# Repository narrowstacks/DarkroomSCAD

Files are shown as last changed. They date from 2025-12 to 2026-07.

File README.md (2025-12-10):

# DarkroomSCAD

## Open source 3D models for darkroom equipment

This project provides a collection of open-source 3D models for darkroom equipment, designed using OpenSCAD. The models are parametric, allowing for customization to fit various needs and film formats. Whether you need negative carriers, film developing tools, or other darkroom accessories, this library aims to provide a versatile and adaptable set of designs for the analog photography community.

## Getting Started

These instructions will help you get a copy of the project up and running on your local machine for development and testing purposes.

### Prerequisites

Before you begin, ensure you have the following installed and configured:

- **OpenSCAD (Nightly Build):** This project requires features available in the nightly builds of OpenSCAD. The latest stable release is not compatible. You can find the nightly builds on the [OpenSCAD downloads page](https://openscad.org/downloads.html) (look further down the page).
- **BOSL2 Library:** This project relies on the BOSL2 library. You can find it at [https://github.com/revarbat/BOSL2](https://github.com/revarbat/BOSL2). Please ensure it is correctly installed and accessible by OpenSCAD.
- **Included Files:** Some `.scad` files may require other specific files to be present in the same directory or a properly configured library path. For example, `omega-d.scad` requires `film-sizes.scad` and `common-carrier-features.scad`.

## Installation

1.  **Download OpenSCAD:**
    - Go to the [OpenSCAD downloads page](https://openscad.org/downloads.html).
    - Download and install the **latest nightly build** suitable for your operating system.
2.  **Install BOSL2 Library:**
    - Follow the installation instructions provided on the [BOSL2 GitHub repository](https://github.com/revarbat/BOSL2). This typically involves cloning the repository or downloading a release and placing it in your OpenSCAD libraries folder.
3.  **Project Files:**
    - Clone or download this repository.
    - Ensure that any accompanying `.scad` files (like `film-sizes.scad` or `common-carrier-features.scad`) are located where the main `.scad` files can find them (e.g., in the same directory or a common library folder).

## Configuration

For optimal performance and to ensure all features work correctly, please configure the following in OpenSCAD:

1.  **Enable Text Metrics:**
    - Go to OpenSCAD `Preferences`.
    - Under the `Features` tab (or similar, depending on the OpenSCAD version).
    - Ensure that `textmetrics` is enabled.
2.  **Set 3D Rendering Engine:**
    - Go to OpenSCAD `Preferences`.
    - Change the `3D rendering engine` to `"Manifold (new/fast)"`. This can significantly speed up the rendering of complex files.

## Usage

To use the `.scad` files in this project:

1.  **Open the File:** Open the desired `.scad` file (e.g., `negative_carriers/carrier.scad`) in OpenSCAD.
2.  **Customize Parameters:** Most `.scad` files will have a section at the top for customization. You can adjust these parameters to suit your needs. 
    - _(Refer to the specific `.scad` file for a full list of available parameters and their descriptions.)_
3.  **Render and Export:**
    - Once customized, you can preview the model in OpenSCAD (usually by pressing F5 for preview or F6 to render).
    - To generate an STL file for 3D printing, choose `File > Export > Export as STL...`.

## Contributing

Contributions are welcome! If you'd like to contribute, please follow these general guidelines:

- **Fork the Repository:** Start by forking the main repository.
- **Create a Branch:** Create a new branch for your feature or bug fix.
- **Code Style:** Try to maintain a consistent code style with the existing codebase. Comment your code where necessary.
- **Test Your Changes:** Ensure your changes work as expected and do not introduce new issues.
- **Submit a Pull Request:** Once your changes are ready, submit a pull request with a clear description of the changes and why they were made.

## License

[This project is licensed under the MIT License.](LICENSE)

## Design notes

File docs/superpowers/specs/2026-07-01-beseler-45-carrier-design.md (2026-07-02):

# Beseler 45 Negative Carrier — Design Spec

**Date:** 2026-07-01
**Status:** Implemented

## Goal

Add a fully working `beseler-45` carrier type to the DarkroomSCAD generator,
replacing the current "not yet implemented" placeholder. The Beseler 45 is a
round, hinged clamshell carrier for the Beseler 45-series (4×5) enlargers. Our
printed version reproduces it as **two separate peg-mated boards** (no hinge).

The implementation follows the existing `beseler-23c` carrier as its template:
round body + protruding handle + handle-mounted text + the shared universal
assembly pipeline. The Beseler 45 adds one thing the 23c does not have: a
second, fixed peg system for enlarger alignment / board stacking.

## Reference dimensions

From `negative-carriers/beseler-45-dimensions.md` and scans of the physical
top/bottom boards:

- Body diameter: **210 mm** (radius 105)
- Handle: **29 mm** wide × **50.5 mm** long
- Board thickness (each half): **2.5 mm** (all other carriers are 2 mm)
- Corner align/stack pegs: **Ø4.6 mm**, **119.7 mm** center-to-center square
  (so each peg sits at ±59.85 mm on X and Y)
- Corner peg holes in the top board: **Ø6 mm**

## Decisions (resolved during brainstorming)

1. **Two peg systems, both modeled:**
   - *Film pegs* — the existing film-format-driven registration pegs (same code
     path as omega/lpl/23c). They register the film and mate the two halves.
     Honor the `Printed_or_Heat_Set_Pegs` option as usual.
   - *Corner align/stack pegs* — new, fixed 119.7 mm square, Ø4.6 mm. The
     **bottom** board carries pegs that protrude **down only (~2 mm)** to seat
     into the enlarger, with a domed (rounded) tip for easy insertion; the upper
     end stays flush inside the board. The **top** board's matching Ø6 mm corner
     holes are **stacking holes** — they receive the down-pegs of another
     carrier stacked on top. Always present, independent of the film-peg style.
     (Earlier revisions had the peg protrude up into the top board as well; that
     was dropped — the film pegs mate the two halves, the corner pegs only
     handle enlarger seating + stacking.)
2. **No alignment board.** The corner pegs are the enlarger alignment; the
   `beseler-45` dispatch forces `Alignment_Board = false` and skips the
   omega/lpl screw-footprint holes. The 4 corner rivets on the real part are
   construction fasteners and are not modeled.
3. **No hinge.** Top and bottom print as two separate pieces, mated by pegs.
4. **No hang hole; solid handle** (matches the 23c).
5. **Handle text** — owner/type etch on the **top (+Y)** handle. Same idea as the
   23c but positioned on the top handle instead of the 23c's −X handle, so it
   needs its own positioning branch (see below).
   - **As implemented:** `get_text_rotation` uses `[0, 0, 90]`, as planned. But
     since `universal-carrier-assembly.scad` applies the transforms as
     `rotate(rotation) translate(position)` — i.e. rotation is the *outer*
     transform — the pre-rotation position tuple in `calculate_text_position`
     had to be swapped to `[handle_mid_y, -x_base, z_position]` (rather than
     `[x_base, handle_mid_y, z_position]`) so that `R(90°) * [a, b] = [-b, a]`
     lands the text at the intended world position on the top handle. Verified
     by the 4×5 renders in Task 4: text sits correctly on the top handle with
     no rotation-composition drift.
6. **4×5 is landscape-only.** For the Beseler 45, 4×5 must render landscape —
   the 5″ (long) edge parallel to the bottom hinge line (i.e. the long edges on
   the top and bottom), hinge at the bottom, handle at the top. This is already
   the effective behavior: 4×5 is globally forced to the code's `"vertical"`
   effective orientation, which yields `cuboid([120, 95])` = 120 mm along X ×
   95 mm along Y = landscape with the long edges horizontal, and the Orientation
   control is ignored for 4×5. So **no orientation-logic change is required** —
   the requirement is satisfied by placing the handle at the top (decision 5/
   base shape) and must be **confirmed visually** during validation.

## Architecture

The Beseler 45 slots into the existing modular pipeline exactly like the 23c,
with a single carrier-type-gated addition for the corner pegs.

### New file: `src/beseler-45-base-shape.scad`

Pure geometry generator, mirroring `beseler-23c-base-shape.scad`:

- `module beseler_45_base_shape(config, top_or_bottom)`
- Uses shared constants `BESELER_45_DIAMETER` (210) and
  `BESELER_45_HANDLE_WIDTH` (29); handle length 50.5 mm.
- Round body via `cyl(h=CARRIER_HEIGHT, r=DIAMETER/2, rounding=.5, $fn=72)`.
- Handle via a rounded `cuboid`. **Handle placed at the top (+Y)**, NOT on the
  −X side like the 23c. This makes the handle define "top" and the opposite edge
  (−Y) the conceptual hinge/bottom, so the 4×5 landscape opening's long edges
  land on the top/bottom. No hang hole.
- Carrier height comes from `get_carrier_height("beseler-45")` = 2.5.

### `src/carrier-configs.scad`

- **Fix bug:** `BESELER_45_DIAMETER = 105` → **`210`** (the base-shape convention
  is `r = DIAMETER/2`; 105 would produce a half-size disc).
- `get_carrier_height`: return `BESELER_45_THICKNESS` (2.5) for `beseler-45`
  (currently everything returns the universal 2). Verify no downstream
  calculation assumes a 2 mm height for this carrier.
- `get_top_peg_hole_z_offset`: give `beseler-45` a value (mirror the 23c's `1`
  unless testing shows otherwise).
- Text: add `beseler-45` to `_get_text_settings` and add a `beseler-45` branch in
  `calculate_text_position` that mounts the text on the **top (+Y)** handle
  (owner/type stacked along the handle's Y length, centered in X), plus a
  `get_text_rotation` case (horizontal text reading left-to-right across the top
  handle). This differs from the 23c branch, which mounts text on the −X handle.
  Ensure the text-feature gate (`_is_full_feature_carrier` /
  `carrier_supports_multi_material_text`) allows beseler-45 text without
  re-enabling alignment-board support.
- Add new constants for the corner pegs:
  - `BESELER_45_ALIGN_PEG_SPACING = 119.7` (center-to-center)
  - `BESELER_45_ALIGN_PEG_DIAMETER = 4.6`
  - `BESELER_45_ALIGN_PEG_HOLE_DIAMETER = 6`
  - up/down protrusion heights (sane defaults, ~4 mm each), tunable.

### `src/common/universal-carrier-assembly.scad`

- `include <../beseler-45-base-shape.scad>`.
- Add a `beseler-45` branch in `generate_universal_base_shape`.
- New module (e.g. `generate_beseler45_corner_pegs()`), gated to
  `carrier_type == "beseler-45"`:
  - **Bottom** assembly: union the 4 corner pegs (protrude down + up).
  - **Top** assembly: subtract the 4 Ø6 mm corner holes.
  - Placed inside the assembly modules so it inherits the
    `Flip_Bottom_For_Printing` rotation. Independent of the film-peg z logic —
    the corner peg needs explicit down/up protrusion, not the film-peg offset.

### `carrier.scad`

- `include <src/beseler-45-base-shape.scad>`.
- Replace the placeholder `assert` branch (currently ~lines 216–218) with a real
  dispatch. Reuse `dispatch_to_universal_assembly` but force
  `_alignment_board = false` and `_alignment_board_type = "none"`, so the corner
  pegs are the only alignment feature. Add `beseler-45` to the standard-carrier
  branch or give it its own branch.

## Component boundaries

- **Base shape** (`beseler-45-base-shape.scad`): knows only the disc + handle
  outline. No openings, no pegs. Depends on the shared diameter/handle
  constants.
- **Corner pegs** (in the assembly layer): a self-contained feature that adds
  pegs (bottom) or holes (top) at fixed positions. Depends only on the corner
  peg constants and `top_or_bottom`.
- **Film pegs / opening / text / dispatch**: unchanged shared machinery; the
  Beseler 45 is just another carrier type flowing through it.

## Testing / validation

- Open `carrier.scad` in OpenSCAD, set `Carrier_Type = "beseler-45"`.
- Render **top** and **bottom** for several formats (35mm, 6x6, 6x9, 4x5) in
  both orientations. Verify:
  - Disc is 210 mm across, 2.5 mm thick, handle 29 mm wide, handle at the top.
  - Film pegs track the format and mate top↔bottom.
  - Bottom board shows 4 corner pegs (down + up); top board shows 4 Ø6 mm holes
    at the matching 119.7 mm square. Corner pegs clear the opening at every
    format including 4×5.
  - **4×5 renders landscape** — long (120 mm) edges on the top and bottom
    (parallel to the −Y hinge line), handle at the top; the Orientation control
    does not change 4×5.
  - No alignment-board geometry or screw-footprint holes appear.
  - Handle text etches correctly (owner + type) on the top handle.
  - `Flip_Bottom_For_Printing` flips the bottom board with its corner pegs.
- Confirm the other carrier types (omega-d, lpl, 23c, test frame) still render
  unchanged.

## Deferred / out of scope

- Hinge, hang hole, and the 4 construction rivets are intentionally not modeled.

## Resolved non-issues

- **Corner pegs vs. 4×5 opening:** no collision. The pegs sit on the diagonal
  corners at (±59.85, ±59.85); the largest opening (4×5 landscape) reaches only
  (60, 47.5). A peg would clip the opening only if both its X and Y ranges
  crossed the opening, but at 4×5 the peg's Y (59.85) clears the opening's
  47.5 mm half-height by ~10 mm. Clears at every format.

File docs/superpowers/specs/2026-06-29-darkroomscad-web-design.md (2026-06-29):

# DarkroomSCAD Web — Design Spec

**Date:** 2026-06-29
**Status:** Approved (brainstorming complete; next step: implementation plan)
**Author:** Aaron + Claude

## Summary

A standalone website that lets analog photographers configure and export 3D-printable
negative carriers from the DarkroomSCAD parametric models — without touching code. Users
pick their enlarger, film format, name/text, font, and options through a guided form, see a
live 3D preview, and download print-ready STL files. The site runs OpenSCAD entirely in the
browser via WebAssembly and deploys to Vercel as an effectively static app (no backend, no
per-render server cost).

This lives in a **new, separate repository** (`darkroomscad-web`) that pulls `.scad` source
from the DarkroomSCAD repo at a pinned ref. This spec document is committed to the
DarkroomSCAD repo as the planning artifact of record.

## Goals

- Non-technical photographers can produce a working carrier STL set in a few clicks.
- Live, interactive 3D preview that updates as parameters change.
- Export the complete set of parts needed to print a real carrier (top + bottom +
  alignment board + multi-material text parts as applicable).
- Visual design that feels like a sibling to [dorkroom](https://dorkroom.art).
- Architecture extensible to other DarkroomSCAD product families (lens boards, Paterson
  tank, thermometer holder) later — but ship **negative carriers only** first.

## Non-Goals (v1)

- No in-browser code editor / SCAD source editing (guided customizer only).
- No product families beyond negative carriers (architect for extension; don't build yet).
- No server-side / serverless rendering (explicitly rejected — see Decisions).
- No user accounts, saved configs server-side, or e-commerce.

## Key Decisions (from brainstorming)

| Decision | Choice | Rationale |
|---|---|---|
| UX model | **Guided customizer** (no code editor) | Audience is photographers, not coders; product feel |
| Catalog scope | **Negative carriers only**, extensible | Most complex/used design; ship focused |
| 3D preview | **Live in-browser preview** | Best product feel; WASM makes it free/client-side |
| File sync | **Build-time fetch/copy script** | Reproducible, pinned, separate repos stay decoupled |
| Export unit | **ZIP (default) or individual files, user choice** | ZIP matches how carriers are actually printed |
| Rendering | **Fully client-side WASM** (Approach A) | No backend, infinite scale, zero render cost |
| Engine | **Official OpenSCAD 2025.03.25 prebuilt WASM** (Manifold + textmetrics) | Importable factory; ~7-8× faster than fast-csg |
| Framework | **Next.js (App Router) on Vercel** | Native Vercel fit; match dorkroom's *look*, not its stack |

### Rejected approaches

- **Serverless rendering (Approach B):** native OpenSCAD in Vercel functions → cold starts,
  function timeouts on large (4x5) renders, per-render cost. Loses the static-site advantage.
- **Fork openscad-playground (Approach C):** architected around a Monaco editor + PrimeReact,
  fights the clean guided-form UX. Used only as a *reference* for known-good WASM/font setup.

## Architecture

### 1. Repo & stack

New repo `darkroomscad-web`:

- **Next.js (App Router) + TypeScript**, deployed on Vercel (effectively static).
- **react-three-fiber + drei** — 3D viewer.
- **fflate** — client-side ZIP.
- **Tailwind CSS** — styling, with a custom theme mirroring dorkroom's tokens.
- **openscad-wasm** (pinned release) — OpenSCAD in a Web Worker.
- All OpenSCAD execution is client-side in a Web Worker. No backend.

### 2. File-sync & build pipeline

`scripts/sync-scad.ts`, run at build time:

- Fetches `carrier.scad` + `src/**` from the DarkroomSCAD repo at a **pinned ref**
  (`DARKROOMSCAD_REF` env var, default a tag/commit SHA). Supports `--local ../DarkroomSCAD`
  for local dev against a working tree.
- Writes the SCAD tree into `public/scad/` (mounted into the WASM virtual filesystem).
- Parses `carrier.scad`'s customizer annotations (`/* [Section] */`, `// [opt,opt]` dropdowns,
  numeric ranges, defaults, comments-as-help) into `generated/param-schema.json`.

Pinning the ref makes builds reproducible; updating the design is a deliberate ref bump.

### 3. Parameter system (auto-parse + curation overlay)

Two layers keep the form both in-sync and clean:

- **`generated/param-schema.json`** — raw truth, auto-derived from `carrier.scad`.
- **`config/carrier-ui.ts`** — hand-maintained curation overlay controlling:
  - Which params are exposed vs. hidden (e.g. hide `TEXT_ETCH_OVEREXTRUDE`; tuck raw text
    offsets behind an "Advanced" disclosure).
  - Friendly labels, help text, grouping, order, step sizes.
  - **Fonts:** replace the free-text `Fontface` param with a dropdown of **bundled open
    fonts only** (we can only render fonts mounted into the WASM FS). The DarkroomSCAD default
    `Lucida Console` is proprietary and must be remapped to a bundled font (e.g. a Liberation
    or DejaVu mono).
  - Conditional visibility: Custom Film Format fields only when `Film_Format=="custom"`;
    `Alignment_Board_Type` only when `Alignment_Board==true`; etc.

A **build-time consistency check** fails the build if the overlay references a param that no
longer exists in the generated schema — so renaming a parameter in the SCAD source can't
silently break the site.

### 4. WASM render engine

`lib/openscad/worker.ts` — a Web Worker wrapping a **pinned `openscad-wasm` release**
(manifold backend; must be a `textmetrics`-capable, nightly-tracking build). On init it mounts
a virtual filesystem containing:

- The synced SCAD tree (`carrier.scad` as the main file, `src/` relative to it).
- **BOSL2** (pinned version) on the OpenSCAD library path.
- **Bundled fonts** + fontconfig so `text()` and `textmetrics()` resolve.

Render API:

```ts
render({ params, quality, part }) -> { stl: Uint8Array, log: string, durationMs: number }
```

- Parameters passed via a written **params JSON** (OpenSCAD customizer parameter set,
  `-p params.json -P set`) for robust escaping of names/strings.
- Manifold backend; `quality` maps to `Render_Quality` + `$fn`.
- Worker **serializes** renders and supports **cancellation** (newest request wins / debounced).

### 5. Preview & viewer

- On parameter change (debounced ~400ms): request a **fast preview** render
  (`Render_Quality="preview"`, low `$fn`, single representative part).
- Resulting STL streams into a **react-three-fiber** viewer: orbit/zoom, grid, auto-fit,
  themed materials.
- A subtle "preview quality" badge. Full-quality renders happen at export time.
- WASM load + first render show a friendly progress state.

### 6. Export

Export panel offers **ZIP (default)** or **individual files**:

- **ZIP:** enumerate the parts needed from the current config — top, bottom, alignment board
  (if enabled), separate text parts (if multi-material enabled) — run a **full-quality render
  per part** (with appropriate `Top_or_Bottom` / `_WhichPart` overrides), name each
  meaningfully (e.g. `omega-d_35mm_vertical_top.stl`), and bundle via fflate with progress.
- **Individual:** pick a single part, download one STL.
- Filenames encode carrier type / film format / orientation / part.

### 7. Error handling

- OpenSCAD compile/render errors (e.g. invalid custom dimensions) are caught in the worker
  and surfaced as readable inline messages — **never a silent empty download**.
- WASM-load failure shows an explicit fallback message (with browser/WebAssembly guidance).
- Empty/degenerate geometry (zero-size STL) is detected and reported rather than exported.

### 8. Visual direction (aligned to dorkroom)

Adopt dorkroom's design language so the two read as a family. (Match the *look and theme
tokens*, not its Vite/TanStack framework — we stay on Next.js for Vercel fit.)

- **Typography:** `Fraunces` (variable serif) for display/headings, `Montserrat` (variable
  sans) for UI/body.
- **Theme system with parity** via CSS custom properties + a theme toggle:
  - **Dark (default):** bg `#09090b`, surfaces `#121214` / `#1c1c1f`; accents mint
    `#6ef3a4` (primary), sky `#7dd6ff`, coral `#f99f96`, lime `#e5ff7d`; text
    `#ffffff` → `#e4e4e7` → `#a1a1aa` → `#71717a`; borders `rgba(255,255,255,0.2|0.1|0.05)`.
  - **Light:** bg `#ffffff`, surfaces `#f8f9fa` / `#f1f3f4`; accents `#2d7a4a`, `#1e6091`,
    `#c4524a`, `#8b9c2e`.
  - **Darkroom safelight:** pure black `#000000`, red-only palette
    (`#ff0000` / `#a90000` / `#920000` / `#820000`) — usable under a safelight.
  - **High-contrast** (e-ink friendly).
- **Semantic colors:** success = mint, warning = lime, error = coral, info = sky — reused for
  render status and error messages.
- **3D viewer:** map materials to theme visualization tokens (model `#666`, grid/edges
  `#353535`, overlay `rgba(0,0,0,0.5)`) so the preview sits in the palette.
- **Component feel:** dorkroom's calculator aesthetic — clean surface cards, subtle
  white-alpha borders, gradient accent cards for primary actions/sections.

### 9. Testing

- **Unit:** customizer-annotation parser (deterministic fixtures); schema/overlay
  consistency check.
- **Integration (headless):** worker renders a known config → assert a non-empty, valid STL;
  one render per carrier type as a smoke test.
- **E2E (later):** Playwright happy path (configure → preview → export ZIP).

## Open Risks (validate early in implementation; not design blockers)

1. **`textmetrics` in WASM:** the chosen `openscad-wasm` release must have `textmetrics`
   enabled, or the carrier's text centering breaks. Fallback: a small JS metrics shim that
   computes centering offsets and passes them as params. Validate before deep UI work.
2. **BOSL2 + nightly features in the WASM build:** confirm the carrier renders end-to-end
   (BOSL2 attachables, etc.) in the pinned build.
3. **Font fidelity:** centering via `textmetrics` depends on the *actual rendered font*;
   ensure the bundled font used for metrics is the one used for geometry.

## Future Extensions (out of scope for v1)

- Additional product families (lens boards, Paterson tank, thermometer holder) via the same
  schema + overlay + worker pipeline — each gets its own main `.scad` and UI overlay.
- Shareable config URLs (encode params in the hash/query).
- PWA / offline support.

> **Update 2026-06-29 (implementation):** Engine is the **official prebuilt OpenSCAD 2025.03.25
> WASM build** (files.openscad.org/playground) — a clean importable factory shipping **both
> Manifold and textmetrics**. (Briefly shipped on scadder's fast-csg build, then upgraded the same
> day after discovering the playground's prebuilt-binary source.) Open Risk #1 (textmetrics) is
> **RETIRED** and the Manifold requirement is **MET**. Carrier renders verified headlessly + in
> browser (~4.4s). See the plan's "Amendment — 2026-06-29" → RESOLUTION.

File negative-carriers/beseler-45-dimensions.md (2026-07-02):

# Beseler 45 Dimensions
- Radius = `105mm`
- Diameter = `210mm`
- Handle length = `50.5mm`
- Handle width = `29mm`
- Top/Bottom Thickness (each) = `2.5mm`

- # Peg Layout

- Peg diameter: `4.6mm`
- Peg radius: `2.3mm`
- Top Carrier Stacking Peg Holes Diameter = `6mm`
- Measured outer-to-outer peg distance: `124.3mm`
- Peg center-to-center spacing: `119.7mm`
- Inner edge-to-inner edge distance: `115.1mm`

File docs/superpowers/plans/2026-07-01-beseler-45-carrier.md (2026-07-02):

# Beseler 45 Carrier Implementation Plan

> **For agentic workers:** REQUIRED SUB-SKILL: Use superpowers:subagent-driven-development (recommended) or superpowers:executing-plans to implement this plan task-by-task. Steps use checkbox (`- [ ]`) syntax for tracking.

**Goal:** Add a fully working `beseler-45` carrier type — round Ø210 mm body, top handle, film-format pegs, a fixed corner alignment/stacking peg system, and handle text — replacing the current "not yet implemented" placeholder.

**Architecture:** The Beseler 45 flows through the existing universal carrier assembly like the Beseler 23C (round base shape + handle + shared film opening / pegs / text), with three carrier-specific additions: 2.5 mm board thickness, a new fixed 4-corner alignment/stacking peg system (bottom board = pegs protruding down+up, top board = Ø6 mm holes), and top-handle text. No alignment board (the corner pegs are the enlarger alignment).

**Tech Stack:** OpenSCAD (2025.05.02, nightly-style features), BOSL2 library. No unit-test framework — verification is headless CLI renders (must exit 0 and produce a non-empty STL) plus top-view PNG snapshots and explicit visual checks.

## Global Constraints

- **Spec:** `docs/superpowers/specs/2026-07-01-beseler-45-carrier-design.md` (authoritative).
- **Body diameter:** 210 mm (radius 105). **Handle:** 29 mm wide × 50.5 mm protruding, at the **top (+Y)**. **Board thickness:** 2.5 mm each half.
- **Corner align/stack pegs:** Ø4.6 mm pegs, **119.7 mm** center-to-center square (±59.85), **Ø6 mm** holes in the top board.
- **No alignment board, no hinge, no hang hole, solid handle.** 4×5 is landscape-only (long edges on top/bottom), guaranteed by the global 4×5 forced orientation + handle-at-top.
- **BOSL2 include stays only at the entry point** (`carrier.scad`); sub-files must NOT `include <BOSL2/std.scad>` (only the commented "uncomment to preview alone" line, matching sibling files).
- **OpenSCAD binary (for all verification commands):**
  `OSC="/Applications/OpenSCAD.app/Contents/MacOS/OpenSCAD"`
- **All render commands run from the `negative-carriers/` directory** (so `carrier.scad` and its relative includes resolve; BOSL2 resolves from the user library path).
- **Do not commit** the scratchpad render outputs. Write them under
  `/private/tmp/claude-501/-Users-aaronanderson-GitHub-DarkroomSCAD/abeb5a9a-23b4-4f55-b805-3737b94776aa/scratchpad` (referred to below as `$OUT`).
- **Not in scope / no change needed:** `carrier-baked.scad` (the fast-preview path) intentionally covers only omega-d / lpl / beseler-23c and routes every other carrier to the exact parametric path, so beseler-45 needs no baked wiring.

---

## File Structure

- **Create** `negative-carriers/src/beseler-45-base-shape.scad` — pure geometry: round body + top handle. One responsibility: the Beseler 45 outline. Mirrors `beseler-23c-base-shape.scad`.
- **Modify** `negative-carriers/src/carrier-configs.scad` — fix the diameter constant, add per-carrier height/peg-z, add corner-peg constants, add beseler-45 text-position/rotation.
- **Modify** `negative-carriers/src/common/universal-carrier-assembly.scad` — include the new base shape, dispatch to it, and add the corner-peg feature modules + gated calls.
- **Modify** `negative-carriers/carrier.scad` — include the new base shape, replace the placeholder assert with a real dispatch (board forced off).

---

## Task 1: Renderable Beseler 45 body (config + base shape + dispatch)

**Deliverable:** `Carrier_Type="beseler-45"` renders a round Ø210 mm carrier with a top handle, film opening, and format-driven film pegs — top and bottom halves — without error. (Corner pegs and custom text come in later tasks.)

**Files:**
- Create: `negative-carriers/src/beseler-45-base-shape.scad`
- Modify: `negative-carriers/src/carrier-configs.scad` (diameter fix, height, top-peg z-offset)
- Modify: `negative-carriers/src/common/universal-carrier-assembly.scad` (include + base-shape dispatch)
- Modify: `negative-carriers/carrier.scad` (include + dispatch branch)

**Interfaces:**
- Produces: `module beseler_45_base_shape(config, top_or_bottom)` — round body (Ø `BESELER_45_DIAMETER`) + handle at +Y; used by `generate_universal_base_shape`.
- Produces: `get_carrier_height("beseler-45") == 2.5` (= `BESELER_45_THICKNESS`), consumed by the assembly and by Task 2's corner-peg modules.
- Consumes: existing `BESELER_45_DIAMETER`, `BESELER_45_HANDLE_WIDTH`, `BESELER_45_THICKNESS` constants (already present in `carrier-configs.scad`).

- [ ] **Step 1: Confirm the current placeholder fails (RED)**

Run (from `negative-carriers/`):
```bash
OSC="/Applications/OpenSCAD.app/Contents/MacOS/OpenSCAD"
OUT="/private/tmp/claude-501/-Users-aaronanderson-GitHub-DarkroomSCAD/abeb5a9a-23b4-4f55-b805-3737b94776aa/scratchpad"
"$OSC" -o "$OUT/b45-top.stl" -D 'Render_Quality="preview"' -D 'Carrier_Type="beseler-45"' -D 'Top_or_Bottom="top"' carrier.scad 2>&1 | grep -i "not yet implemented"
```
Expected: prints the `CARRIER TYPE ERROR: 'beseler-45' is not yet implemented...` assert message; no STL produced.

- [ ] **Step 2: Fix the diameter bug and add per-carrier height + peg-z in `carrier-configs.scad`**

Change `BESELER_45_DIAMETER = 105;` (line ~79) to:
```openscad
BESELER_45_DIAMETER = 210;
```

Replace `get_carrier_height` (lines ~32) with:
```openscad
function get_carrier_height(carrier_type) =
    (carrier_type == "beseler-45") ? BESELER_45_THICKNESS
    : UNIVERSAL_CARRIER_HEIGHT;
```

Replace `get_top_peg_hole_z_offset` (lines ~39-42) with (offset `2`, not the
23c's `1`, so the top film-peg holes punch fully through the 2.5 mm board —
offset `1` leaves them blind at this thickness):
```openscad
function get_top_peg_hole_z_offset(carrier_type) =
    (carrier_type == "omega-d") ? 2
    : (carrier_type == "beseler-23c") ? 1
    // 2.5mm-thick board: offset 2 (not the 23c's 1) so the top film-peg holes
    // punch fully through — a 1 would leave them blind at this thickness.
    : (carrier_type == "beseler-45") ? 2
    : 2;
```

- [ ] **Step 3: Create `src/beseler-45-base-shape.scad`**

```openscad
// Beseler 45 Base Shape Generator
// Pure geometry generator for Beseler 45 enlarger carrier base shapes
// Handles only the physical shape and handle

// BOSL2 is included once at the entry point (carrier.scad) — OpenSCAD re-parses
// every include with no dedup, so re-including the ~80k-line library here would
// add seconds per render. Uncomment to render/preview this file by itself:
// include <BOSL2/std.scad>
include <carrier-configs.scad>

/**
 * Beseler 45 base shape module
 * Generates the round Beseler 45 carrier body with a handle at the top (+Y).
 * The handle sits opposite the (conceptual) hinge edge so the 4x5 landscape
 * opening's long edges land on the top/bottom. Uses shared BESELER_45_DIAMETER
 * and BESELER_45_HANDLE_WIDTH from carrier-configs.scad.
 *
 * @param config - Configuration array (currently unused; reserved for future overrides)
 * @param top_or_bottom - "top" or "bottom" (no geometric difference; kept for interface consistency)
 */
module beseler_45_base_shape(config, top_or_bottom) {
    CARRIER_HEIGHT = get_carrier_height("beseler-45");

    CARRIER_DIAMETER = BESELER_45_DIAMETER;   // 210
    HANDLE_WIDTH = BESELER_45_HANDLE_WIDTH;   // 29
    HANDLE_LENGTH = 50.5;                     // protruding length beyond the disc edge

    // Handle at the top (+Y). The cuboid is 2*HANDLE_LENGTH long and centred on
    // the disc edge, so it protrudes exactly HANDLE_LENGTH and overlaps the disc
    // by the same amount for a clean manifold union.
    module handle() {
        translate([0, CARRIER_DIAMETER / 2, 0])
            cuboid([HANDLE_WIDTH, HANDLE_LENGTH * 2, CARRIER_HEIGHT], anchor=CENTER, rounding=.5);
    }

    // $fn=72 on a 210mm circle gives ~9mm segments, well below visible thresholds.
    BODY_FN = 72;

    module base_geometry() {
        cyl(h=CARRIER_HEIGHT, r=CARRIER_DIAMETER / 2, center=true, rounding=.5, $fn=BODY_FN);
    }

    // render() caches geometry for faster subsequent previews
    render() union() {
        base_geometry();
        handle();
    }
}
```

- [ ] **Step 4: Wire the base shape into `src/common/universal-carrier-assembly.scad`**

After the existing base-shape includes (after `include <../beseler-23c-base-shape.scad>`, line ~19) add:
```openscad
include <../beseler-45-base-shape.scad>
```

In `generate_universal_base_shape` (lines ~292-305), add a branch before the fallback `else`:
```openscad
        } else if (carrier_type == "beseler-45") {
            beseler_45_base_shape(config, top_or_bottom);
        } else if (is_test_frame_type(carrier_type)) {
```
(i.e. insert the `beseler-45` branch immediately before the existing `is_test_frame_type` branch.)

- [ ] **Step 5: Wire the include + dispatch into `carrier.scad`**

After `include <src/beseler-23c-base-shape.scad>` (line ~28) add:
```openscad
include <src/beseler-45-base-shape.scad>
```

Replace the placeholder branch (lines ~216-218):
```openscad
} else if (Carrier_Type == "beseler-45") {
    // Future implementation placeholder
    assert(false, str("CARRIER TYPE ERROR: '", Carrier_Type, "' is not yet implemented. Use one of: omega-d, lpl-saunders-45xx, beseler-23c"));
}
```
with a real dispatch that forces the alignment board off (the corner pegs are the enlarger alignment):
```openscad
} else if (Carrier_Type == "beseler-45") {
    // Beseler 45: no alignment board — the fixed corner pegs align it in the enlarger.
    dispatch_to_universal_assembly(
        _alignment_board=false,
        _alignment_board_type="none"
    );
}
```

- [ ] **Step 6: Render top + bottom (text off) to verify it builds (GREEN)**

Run (from `negative-carriers/`):
```bash
OSC="/Applications/OpenSCAD.app/Contents/MacOS/OpenSCAD"
OUT="/private/tmp/claude-501/-Users-aaronanderson-GitHub-DarkroomSCAD/abeb5a9a-23b4-4f55-b805-3737b94776aa/scratchpad"
for tb in top bottom; do
  "$OSC" -o "$OUT/b45-$tb.stl" -D 'Render_Quality="preview"' \
    -D 'Carrier_Type="beseler-45"' -D "Top_or_Bottom=\"$tb\"" \
    -D 'Enable_Owner_Name_Etch=false' -D 'Enable_Type_Name_Etch=false' \
    -D 'Printed_or_Heat_Set_Pegs="printed"' carrier.scad 2>&1 | tail -2
  ls -la "$OUT/b45-$tb.stl"
done
```
Expected: each render exits without an assert/error, prints a "Top level object is a 3D object" summary, and produces a non-empty (`> 0` byte) `.stl`.

- [ ] **Step 7: Render a top-view PNG and eyeball the body**

```bash
OSC="/Applications/OpenSCAD.app/Contents/MacOS/OpenSCAD"
OUT="/private/tmp/claude-501/-Users-aaronanderson-GitHub-DarkroomSCAD/abeb5a9a-23b4-4f55-b805-3737b94776aa/scratchpad"
"$OSC" -o "$OUT/b45-top.png" --imgsize=900,900 --projection=ortho --camera=0,0,0,0,0,0,750 \
  -D 'Render_Quality="preview"' -D 'Carrier_Type="beseler-45"' -D 'Top_or_Bottom="top"' \
  -D 'Enable_Owner_Name_Etch=false' -D 'Enable_Type_Name_Etch=false' \
  -D 'Printed_or_Heat_Set_Pegs="printed"' carrier.scad 2>&1 | tail -2
```
Expected/visual check (open `$OUT/b45-top.png`): a round disc with the **handle pointing up (+Y)**, a central film opening, and four film pegs/holes hugging the opening. Disc clearly larger than the 23c (210 vs 160 mm).

- [ ] **Step 8: Commit**

```bash
git add negative-carriers/src/beseler-45-base-shape.scad \
        negative-carriers/src/carrier-configs.scad \
        negative-carriers/src/common/universal-carrier-assembly.scad \
        negative-carriers/carrier.scad
git commit -m "feat(beseler-45): render round body + top handle via universal assembly"
```

---

## Task 2: Corner alignment / stacking pegs

**Deliverable:** The bottom board grows four Ø4.6 mm pegs at the fixed 119.7 mm square, protruding below (enlarger) and above (stacking); the top board gets four matching Ø6 mm through-holes. Film pegs and everything else are unchanged.

**Files:**
- Modify: `negative-carriers/src/carrier-configs.scad` (corner-peg constants)
- Modify: `negative-carriers/src/common/universal-carrier-assembly.scad` (feature modules + gated calls)

**Interfaces:**
- Consumes: `get_carrier_height("beseler-45")` (= 2.5, from Task 1).
- Produces: `module beseler45_corner_pegs()` (additive, bottom) and `module beseler45_corner_peg_holes()` (subtractive, top), both keyed off the new constants.

- [ ] **Step 1: Add corner-peg constants to `carrier-configs.scad`**

Immediately after the existing `BESELER_45_THICKNESS = 2.5;` line (~82) add:
```openscad
// Beseler 45 fixed corner alignment/stacking pegs (independent of film format).
// Bottom board carries the pegs (protrude down into the enlarger + up into the
// top board); the top board receives them with clearance holes.
BESELER_45_ALIGN_PEG_SPACING = 119.7;      // center-to-center square (peg at ±59.85)
BESELER_45_ALIGN_PEG_DIAMETER = 4.6;       // peg diameter
BESELER_45_ALIGN_PEG_HOLE_DIAMETER = 6;    // top-board clearance-hole diameter
BESELER_45_ALIGN_PEG_DOWN = 4;             // protrusion below the bottom face (enlarger)
BESELER_45_ALIGN_PEG_UP = 4;               // protrusion above the top face (into top board)
```

- [ ] **Step 2: Add the feature modules to `universal-carrier-assembly.scad`**

Immediately after the include block (after `include <../carrier-configs.scad>`, line ~22) and before the big `universal_carrier_assembly` doc comment, add:
```openscad
// ============================================================================
// BESELER 45 CORNER ALIGNMENT / STACKING PEGS
// Fixed square (BESELER_45_ALIGN_PEG_SPACING center-to-center). On the BOTTOM
// board the pegs protrude down (seat into the enlarger) and up (into the top
// board). The TOP board receives them with Ø BESELER_45_ALIGN_PEG_HOLE_DIAMETER
// through-holes. Independent of film format and of the film-peg style.
// ============================================================================
module beseler45_corner_pegs() {
    half = BESELER_45_ALIGN_PEG_SPACING / 2;
    r = BESELER_45_ALIGN_PEG_DIAMETER / 2;
    ch = get_carrier_height("beseler-45");
    total_h = BESELER_45_ALIGN_PEG_DOWN + ch + BESELER_45_ALIGN_PEG_UP;
    z_center = (BESELER_45_ALIGN_PEG_UP - BESELER_45_ALIGN_PEG_DOWN) / 2;
    for (xm = [-1, 1]) for (ym = [-1, 1])
        translate([xm * half, ym * half, z_center])
            cylinder(h=total_h, r=r, center=true, $fn=32);
}

module beseler45_corner_peg_holes() {
    half = BESELER_45_ALIGN_PEG_SPACING / 2;
    r = BESELER_45_ALIGN_PEG_HOLE_DIAMETER / 2;
    ch = get_carrier_height("beseler-45");
    for (xm = [-1, 1]) for (ym = [-1, 1])
        translate([xm * half, ym * half, 0])
            cylinder(h=ch + 2, r=r, center=true, $fn=32);
}
```

- [ ] **Step 3: Subtract the holes on the TOP carrier**

In `universal_top_carrier_assembly` (lines ~347-373), inside the `difference()` block, after `generate_universal_directional_arrows();` add:
```openscad
                    generate_universal_directional_arrows();

                    // Beseler 45: clearance holes for the bottom board's corner pegs
                    if (carrier_type == "beseler-45") beseler45_corner_peg_holes();
```

- [ ] **Step 4: Add the pegs on the BOTTOM carrier**

In `universal_bottom_carrier_assembly` (lines ~310-342), inside the `union()`, after the `carrier_base_processing(...) { ... }` block and before/near `generate_universal_alignment_board();` add:
```openscad
                // Add alignment board if enabled
                generate_universal_alignment_board();

                // Beseler 45: fixed corner alignment/stacking pegs (down + up)
                if (carrier_type == "beseler-45") beseler45_corner_pegs();
```

- [ ] **Step 5: Render bottom (pegs) and top (holes) — GREEN**

```bash
OSC="/Applications/OpenSCAD.app/Contents/MacOS/OpenSCAD"
OUT="/private/tmp/claude-501/-Users-aaronanderson-GitHub-DarkroomSCAD/abeb5a9a-23b4-4f55-b805-3737b94776aa/scratchpad"
for tb in top bottom; do
  "$OSC" -o "$OUT/b45-pegs-$tb.stl" -D 'Render_Quality="preview"' \
    -D 'Carrier_Type="beseler-45"' -D "Top_or_Bottom=\"$tb\"" \
    -D 'Flip_Bottom_For_Printing=false' \
    -D 'Enable_Owner_Name_Etch=false' -D 'Enable_Type_Name_Etch=false' \
    -D 'Printed_or_Heat_Set_Pegs="printed"' carrier.scad 2>&1 | tail -2
  "$OSC" -o "$OUT/b45-pegs-$tb.png" --imgsize=900,900 --projection=ortho --camera=0,0,0,0,0,0,750 \
    -D 'Render_Quality="preview"' -D 'Carrier_Type="beseler-45"' -D "Top_or_Bottom=\"$tb\"" \
    -D 'Flip_Bottom_For_Printing=false' \
    -D 'Enable_Owner_Name_Etch=false' -D 'Enable_Type_Name_Etch=false' \
    -D 'Printed_or_Heat_Set_Pegs="printed"' carrier.scad 2>&1 | tail -1
done
```
Expected/visual check:
- `b45-pegs-top.png`: **four holes** at the wide corner square (well outside the film pegs).
- `b45-pegs-bottom.png`: **four solid pegs** at the same corners. (Top-down view shows the peg circles; the down/up protrusion is confirmed in the side view below.)

- [ ] **Step 6: Verify the down+up protrusion with a side-view PNG**

```bash
OSC="/Applications/OpenSCAD.app/Contents/MacOS/OpenSCAD"
OUT="/private/tmp/claude-501/-Users-aaronanderson-GitHub-DarkroomSCAD/abeb5a9a-23b4-4f55-b805-3737b94776aa/scratchpad"
"$OSC" -o "$OUT/b45-pegs-side.png" --imgsize=1000,500 --projection=ortho --camera=0,0,0,90,0,0,750 \
  -D 'Render_Quality="preview"' -D 'Carrier_Type="beseler-45"' -D 'Top_or_Bottom="bottom"' \
  -D 'Flip_Bottom_For_Printing=false' \
  -D 'Enable_Owner_Name_Etch=false' -D 'Enable_Type_Name_Etch=false' \
  -D 'Printed_or_Heat_Set_Pegs="printed"' carrier.scad 2>&1 | tail -1
```
Expected/visual check (`b45-pegs-side.png`, edge-on view): the corner pegs stick out **both** faces of the 2.5 mm bottom board (≈4 mm each side).

- [ ] **Step 7: Commit**

```bash
git add negative-carriers/src/carrier-configs.scad \
        negative-carriers/src/common/universal-carrier-assembly.scad
git commit -m "feat(beseler-45): add fixed corner alignment/stacking pegs (bottom) + holes (top)"
```

---

## Task 3: Handle text on the top handle

**Deliverable:** Owner/type text etches onto the top (+Y) handle, running along the handle length, on both top and bottom carriers, without render errors.

**Files:**
- Modify: `negative-carriers/src/carrier-configs.scad` (`_get_text_settings`, `calculate_text_position`, `get_text_rotation`)

**Interfaces:**
- Consumes: `BESELER_45_DIAMETER`, `BESELER_45_HANDLE_WIDTH` (from configs).
- Produces: a `beseler-45` case in `calculate_text_position` returning a valid `[x, y, z]`, and `get_text_rotation("beseler-45", _) == [0, 0, 90]`. Consumed by both `universal-carrier-assembly.scad` and `carrier-baked.scad` (both call these shared functions).

- [ ] **Step 1: Confirm current text lands via the generic branch (baseline)**

Run:
```bash
OSC="/Applications/OpenSCAD.app/Contents/MacOS/OpenSCAD"
OUT="/private/tmp/claude-501/-Users-aaronanderson-GitHub-DarkroomSCAD/abeb5a9a-23b4-4f55-b805-3737b94776aa/scratchpad"
"$OSC" -o "$OUT/b45-text-before.png" --imgsize=900,900 --projection=ortho --camera=0,0,0,0,0,0,750 \
  -D 'Render_Quality="preview"' -D 'Carrier_Type="beseler-45"' -D 'Top_or_Bottom="top"' \
  -D 'Owner_Name="NARROWSTACKS"' -D 'Printed_or_Heat_Set_Pegs="printed"' carrier.scad 2>&1 | tail -1
```
Expected/visual: text currently renders via the generic edge branch (placed out on the disc body, not on the handle) — this is what we're replacing.

- [ ] **Step 2: Add a `beseler-45` entry to `_get_text_settings`**

In `_get_text_settings` (lines ~60-64) add a `beseler-45` case before the final fallback (the value is unused by the dedicated position branch but must be non-undef):
```openscad
function _get_text_settings(carrier_type) =
    (carrier_type == "omega-d") ? [-90, 69.5, 5]       // rect section is 139mm wide, edge at ~69.5
    : (carrier_type == "lpl-saunders-45xx") ? [-65, 85, 5] // 215mm diameter, text near handle side
    : (carrier_type == "beseler-23c") ? [-65, 60, 5]   // 160mm diameter, text on handle
    : (carrier_type == "beseler-45") ? [0, 105, 5]     // 210mm diameter, text on top handle
    : [0, 60, 5];
```

- [ ] **Step 3: Add a `beseler-45` branch to `calculate_text_position`**

In `calculate_text_position` (lines ~406-436), add a `beseler-45` branch immediately after the `beseler-23c` branch and before the default `let(...)`:
```openscad
    :
    // Beseler 45: text lives on the protruding top (+Y) handle, running along the
    // handle's long (Y) axis (see get_text_rotation → 90°). Owner and type sit as
    // two columns across the 29mm handle width (X).
    (carrier_type == "beseler-45") ?
        let (
            handle_mid_y = BESELER_45_DIAMETER / 2 + 22,   // ~127mm, on the visible handle
            x_base = (text_type == "owner") ? (BESELER_45_HANDLE_WIDTH / 4) : (-BESELER_45_HANDLE_WIDTH / 4)
        ) [x_base, handle_mid_y, z_position]
    :
    // Default handling: position text with equal edge margin from carrier boundary
    let (
```
(The existing `let (` for the default branch stays; you are inserting the `beseler-45 ? ... :` ternary just above it.)

- [ ] **Step 4: Add a `beseler-45` case to `get_text_rotation`**

Replace `get_text_rotation` (lines ~447-449) with:
```openscad
function get_text_rotation(carrier_type, text_type) =
    (carrier_type == "omega-d" || carrier_type == "lpl-saunders-45xx") ? _VERTICAL_TEXT_ROTATION
    : (carrier_type == "beseler-45") ? [0, 0, 90]
    : _HORIZONTAL_TEXT_ROTATION;
```

- [ ] **Step 5: Render top + bottom with text — GREEN**

```bash
OSC="/Applications/OpenSCAD.app/Contents/MacOS/OpenSCAD"
OUT="/private/tmp/claude-501/-Users-aaronanderson-GitHub-DarkroomSCAD/abeb5a9a-23b4-4f55-b805-3737b94776aa/scratchpad"
for tb in top bottom; do
  "$OSC" -o "$OUT/b45-text-$tb.stl" -D 'Render_Quality="preview"' \
    -D 'Carrier_Type="beseler-45"' -D "Top_or_Bottom=\"$tb\"" \
    -D 'Owner_Name="NAME"' -D 'Printed_or_Heat_Set_Pegs="printed"' carrier.scad 2>&1 | tail -2
  "$OSC" -o "$OUT/b45-text-$tb.png" --imgsize=900,900 --projection=ortho --camera=0,0,0,0,0,0,750 \
    -D 'Render_Quality="preview"' -D 'Carrier_Type="beseler-45"' -D "Top_or_Bottom=\"$tb\"" \
    -D 'Flip_Bottom_For_Printing=false' \
    -D 'Owner_Name="NAME"' -D 'Printed_or_Heat_Set_Pegs="printed"' carrier.scad 2>&1 | tail -1
done
```
Expected/visual check: both renders succeed; owner + type text now sit **on the top handle** (two columns running along the handle length). If the text reads upside-down/mirrored for your taste, flip `get_text_rotation` to `[0, 0, 270]` and/or swap the owner/type `x_base` signs — re-render and confirm. (Legibility is a visual judgment; the automated gate is only "renders without error.")

- [ ] **Step 6: Commit**

```bash
git add negative-carriers/src/carrier-configs.scad
git commit -m "feat(beseler-45): etch owner/type text on the top handle"
```

---

## Task 4: 4×5 landscape confirmation + full regression

**Deliverable:** Documented confirmation that beseler-45 4×5 renders landscape with the long edges on the top/bottom and the corner pegs clearing the opening, and that the other carrier types still render unchanged.

**Files:** none (verification only). If 4×5 does NOT render landscape (it should, per the spec), stop and report — do not guess a fix.

- [ ] **Step 1: Render beseler-45 4×5 top + bottom**

```bash
OSC="/Applications/OpenSCAD.app/Contents/MacOS/OpenSCAD"
OUT="/private/tmp/claude-501/-Users-aaronanderson-GitHub-DarkroomSCAD/abeb5a9a-23b4-4f55-b805-3737b94776aa/scratchpad"
for tb in top bottom; do
  "$OSC" -o "$OUT/b45-4x5-$tb.png" --imgsize=900,900 --projection=ortho --camera=0,0,0,0,0,0,750 \
    -D 'Render_Quality="preview"' -D 'Carrier_Type="beseler-45"' -D "Top_or_Bottom=\"$tb\"" \
    -D 'Film_Format="4x5"' -D 'Flip_Bottom_For_Printing=false' \
    -D 'Owner_Name="NAME"' -D 'Printed_or_Heat_Set_Pegs="printed"' carrier.scad 2>&1 | tail -2
done
```
Expected/visual check: the 4×5 opening is **wider than tall** (landscape), its two long edges horizontal (on the top/bottom, parallel to the −Y hinge edge), handle up. The four corner pegs/holes sit clear of the opening (no overlap).

- [ ] **Step 2: Render the whole `carrier.scad` STL for beseler-45 (final smoke test)**

```bash
OSC="/Applications/OpenSCAD.app/Contents/MacOS/OpenSCAD"
OUT="/private/tmp/claude-501/-Users-aaronanderson-GitHub-DarkroomSCAD/abeb5a9a-23b4-4f55-b805-3737b94776aa/scratchpad"
"$OSC" -o "$OUT/b45-final.stl" -D 'Render_Quality="final"' \
  -D 'Carrier_Type="beseler-45"' -D 'Top_or_Bottom="bottom"' \
  -D 'Film_Format="6x6"' carrier.scad 2>&1 | tail -3
ls -la "$OUT/b45-final.stl"
```
Expected: exits without error (default heat-set pegs, no alignment board — must NOT hit the "Alignment board included, so we can't use printed pegs" assert since the board is forced off), produces a non-empty STL.

- [ ] **Step 3: Regression — the other carriers still render**

```bash
OSC="/Applications/OpenSCAD.app/Contents/MacOS/OpenSCAD"
OUT="/private/tmp/claude-501/-Users-aaronanderson-GitHub-DarkroomSCAD/abeb5a9a-23b4-4f55-b805-3737b94776aa/scratchpad"
for ct in omega-d lpl-saunders-45xx beseler-23c frameAndPegTest; do
  "$OSC" -o "$OUT/reg-$ct.stl" -D 'Render_Quality="preview"' \
    -D "Carrier_Type=\"$ct\"" -D 'Top_or_Bottom="bottom"' \
    -D 'Alignment_Board=false' -D 'Printed_or_Heat_Set_Pegs="printed"' carrier.scad 2>&1 | tail -1
  ls -la "$OUT/reg-$ct.stl"
done
```
Expected: all four still render to non-empty STLs (no new errors introduced by the shared-function edits).

- [ ] **Step 4: Update the spec status + note the verified text rotation**

In `docs/superpowers/specs/2026-07-01-beseler-45-carrier-design.md`, change the header `Status:` line to `Implemented` and, if the text rotation was flipped from the planned `[0,0,90]` during Task 3 Step 5, note the final value in the text decision.

- [ ] **Step 5: Commit**

```bash
git add docs/superpowers/specs/2026-07-01-beseler-45-carrier-design.md
git commit -m "docs(beseler-45): mark spec implemented; record verified text rotation"
```

---

## Notes for the implementer

- **OpenSCAD line numbers are approximate** ("lines ~NNN") because earlier edits shift them. Match on the surrounding code shown, not the number.
- **Headless renders print pre-existing warnings** (e.g. `undefined operation` from the omega text path) even on unmodified code — those are not caused by this work. The gate is "no assert/error and a non-empty STL," not "zero warnings."
- **No BOSL2 in sub-files.** `beseler-45-base-shape.scad` uses `cyl`/`cuboid` (BOSL2) but relies on the entry-point include, exactly like `beseler-23c-base-shape.scad`. Keep the commented `// include <BOSL2/std.scad>` line for standalone preview only.
- **`center=true` bodies** put the board at Z ∈ [−1.25, +1.25] (2.5 mm). The corner-peg Z math depends on that; don't change the base shape to anchor at Z=0 bottom without updating `beseler45_corner_pegs`.
- **Do NOT touch the feature-gate functions** (`_is_full_feature_carrier`, `carrier_supports_alignment_board`, `carrier_supports_multi_material_text`, `carrier_supports_test_frames`). They are defined but never called in the `.scad` sources (they exist for the web project), so text etching is NOT gated by them — the universal assembly always etches text. Adding `beseler-45` to `_is_full_feature_carrier` would wrongly advertise alignment-board support, which we don't want.
- **Bottom-carrier text is not mirrored** for beseler-45 (unlike the 23c, which etches its bottom text on the underside). This is intentional for v1: text goes on the top surface of both halves. If the bottom half's text reads mirrored when flipped and that's undesirable, that's a follow-up (add `beseler-45` to the `_etch_on_bottom` handling in `universal-carrier-assembly.scad`), not part of this plan.

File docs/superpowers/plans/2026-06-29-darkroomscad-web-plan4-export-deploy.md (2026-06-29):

# DarkroomSCAD Web — Plan 4: Export & Deploy

> **For agentic workers:** REQUIRED SUB-SKILL: Use superpowers:subagent-driven-development (recommended) or superpowers:executing-plans to implement this plan task-by-task. Steps use checkbox (`- [ ]`) syntax for tracking.

**Goal:** Let users export the complete set of parts needed to print a working carrier (top + bottom, plus multi-material text parts when enabled) as a ZIP (default) or individual STLs, then deploy the site to Vercel sourcing the `.scad` from GitHub at a pinned ref.

**Architecture:** A pure part-enumeration function turns the current config into a list of candidate render jobs (each a `Top_or_Bottom`/`_WhichPart` override at final quality). An export controller renders each job through the existing `RenderClient`, **skips parts that render empty** (so we don't need exact SCAD part-model knowledge — e.g. text only on one half), and bundles the non-empty STLs with `fflate`. The build-time sync script gains a **GitHub-raw pinned-ref fetch** mode so Vercel builds pull the carrier source without a local checkout. No change to the Plan 1 render pipeline or the Plan 2/3 form/preview/theme contracts.

**Tech Stack:** Next.js 15, React 19, TypeScript, `fflate` (ZIP), Vitest, Vercel. Builds on Plans 1-3.

## Global Constraints

- **Repo:** all work in `~/workspace/darkroomscad-web` (`main`, remote `origin` = github.com/narrowstacks/darkroomscad-web). Push at the end of tasks the plan says to push.
- **No backend.** Export + render stay client-side WASM. The deployed site is effectively static (no serverless functions).
- **Reuse Plan 1-3; don't fork.** Consume `RenderClient.render(req)`, `RenderParams`/`RenderResult`, `useCarrierForm().toParams`, the worker (fresh-module-per-render). Do NOT change `render.ts` render args or the worker protocol.
- **Source of truth:** `Carrier_Type`/`Film_Format`/`Orientation`/`Top_or_Bottom`/`_WhichPart`/`Text_As_Separate_Parts`/`Enable_Owner_Name_Etch`/`Enable_Type_Name_Etch` are the params that define the printable parts (verified in the schema).
- **Export quality:** every export job sets `Render_Quality:"final"` (full `$fn`). Preview stays `"preview"`.
- **Empty-part skipping:** the render core throws on a degenerate/empty STL (`byteLength <= 84`). The export controller MUST catch that per-part and skip it (not abort the whole export) — this is how we avoid generating empty text STLs for a half that carries no text.
- **DarkroomSCAD source:** `github.com/narrowstacks/DarkroomSCAD` (PUBLIC); carrier at `negative-carriers/carrier.scad` + `negative-carriers/src/**`. The pinned ref defaults to a specific commit SHA (recorded in config), NOT a moving branch.
- **Deploy is an outward action.** The actual `vercel deploy` / project creation is USER-GATED — the implementer prepares everything and STOPS for the controller/user to run/confirm the deploy. Do not deploy autonomously.
- **Filenames:** parts named `<carrier>_<format>_<orientation>_<part>.stl` (spaces→`-`); ZIP named `<carrier>_<format>_carrier-set.zip`.

---

### Task 1: Part enumeration

Pure logic — full TDD. Turn the form's params into the candidate render jobs for a complete printable set.

**Files:**
- Create: `src/lib/export/part-enumeration.ts`
- Test: `src/lib/export/part-enumeration.test.ts`

**Interfaces:**
- Consumes: `RenderParams` from `@/lib/openscad/types`.
- Produces:
  - `interface PartJob { name: string; params: RenderParams }`
  - `function enumerateParts(form: RenderParams): PartJob[]`
  - Behavior: always both halves (`top`, `bottom`). When `Text_As_Separate_Parts !== true`: one `All` part per half. When `=== true`: a `Base` part per half, plus an `OwnerText` part (only if `Enable_Owner_Name_Etch === true`) and a `TypeText` part (only if `Enable_Type_Name_Etch === true`) per half. Every job sets `Render_Quality:"final"` and the `Top_or_Bottom`/`_WhichPart`/`Text_As_Separate_Parts` overrides. (The alignment board is in-geometry via the `Alignment_Board` param — NOT a separate job. Empty candidate parts are filtered later by the export controller, not here.)

- [ ] **Step 1: Write the failing tests**

Create `src/lib/export/part-enumeration.test.ts`:

```ts
import { describe, it, expect } from "vitest";
import { enumerateParts } from "./part-enumeration";
import type { RenderParams } from "../openscad/types";

const baseForm: RenderParams = {
  Carrier_Type: "omega-d", Film_Format: "35mm", Orientation: "vertical",
  Enable_Owner_Name_Etch: true, Enable_Type_Name_Etch: true,
};

describe("enumerateParts", () => {
  it("single-material: one All part per half (top + bottom), final quality", () => {
    const jobs = enumerateParts({ ...baseForm, Text_As_Separate_Parts: false });
    expect(jobs).toHaveLength(2);
    expect(jobs.map((j) => j.params.Top_or_Bottom)).toEqual(["top", "bottom"]);
    for (const j of jobs) {
      expect(j.params._WhichPart).toBe("All");
      expect(j.params.Render_Quality).toBe("final");
    }
    expect(jobs[0].name).toBe("omega-d_35mm_vertical_top.stl");
  });

  it("multi-material with both etches: Base + OwnerText + TypeText per half (6 jobs)", () => {
    const jobs = enumerateParts({ ...baseForm, Text_As_Separate_Parts: true });
    expect(jobs).toHaveLength(6);
    const whichParts = jobs.filter((j) => j.params.Top_or_Bottom === "top").map((j) => j.params._WhichPart);
    expect(whichParts).toEqual(["Base", "OwnerText", "TypeText"]);
    expect(jobs.find((j) => j.params._WhichPart === "OwnerText")!.name).toContain("owner-text");
  });

  it("multi-material with only the name etch: Base + OwnerText per half (4 jobs, no TypeText)", () => {
    const jobs = enumerateParts({
      ...baseForm, Text_As_Separate_Parts: true,
      Enable_Owner_Name_Etch: true, Enable_Type_Name_Etch: false,
    });
    expect(jobs).toHaveLength(4);
    expect(jobs.some((j) => j.params._WhichPart === "TypeText")).toBe(false);
  });

  it("encodes carrier/format/orientation/part in the filename, spaces dashed", () => {
    const jobs = enumerateParts({ ...baseForm, Film_Format: "6x6 filed", Text_As_Separate_Parts: false });
    expect(jobs[0].name).toBe("omega-d_6x6-filed_vertical_top.stl");
  });
});
```

- [ ] **Step 2: Run to verify failure**

Run: `npm run test -- part-enumeration`
Expected: FAIL — not defined.

- [ ] **Step 3: Implement the enumeration**

Create `src/lib/export/part-enumeration.ts`:

```ts
import type { RenderParams } from "../openscad/types";

export interface PartJob {
  name: string;
  params: RenderParams;
}

function slug(s: string): string {
  return s.replace(/\s+/g, "-");
}

export function enumerateParts(form: RenderParams): PartJob[] {
  const carrier = slug(String(form.Carrier_Type ?? "carrier"));
  const format = slug(String(form.Film_Format ?? "format"));
  const orient = slug(String(form.Orientation ?? "vertical"));
  const multimat = form.Text_As_Separate_Parts === true;

  const job = (half: string, whichPart: string, suffix: string): PartJob => ({
    name: `${carrier}_${format}_${orient}_${half}${suffix}.stl`,
    params: {
      ...form,
      Top_or_Bottom: half,
      _WhichPart: whichPart,
      Text_As_Separate_Parts: multimat,
      Render_Quality: "final",
    },
  });

  const jobs: PartJob[] = [];
  for (const half of ["top", "bottom"]) {
    if (!multimat) {
      jobs.push(job(half, "All", ""));
    } else {
      jobs.push(job(half, "Base", "_base"));
      if (form.Enable_Owner_Name_Etch === true) jobs.push(job(half, "OwnerText", "_owner-text"));
      if (form.Enable_Type_Name_Etch === true) jobs.push(job(half, "TypeText", "_type-text"));
    }
  }
  return jobs;
}
```

- [ ] **Step 4: Run to verify pass**

Run: `npm run test -- part-enumeration`
Expected: PASS (4 tests).

- [ ] **Step 5: Commit**

```bash
git add src/lib/export/part-enumeration.ts src/lib/export/part-enumeration.test.ts
git commit -m "feat(export): part enumeration (top/bottom, multi-material text parts)"
```

---

### Task 2: Export controller (multi-part render + ZIP)

Render each enumerated part, skip empties, bundle with `fflate`. The render-loop + zip-assembly + empty-skip are TDD'd against a fake render client.

**Files:**
- Modify: `package.json` (add `fflate`)
- Create: `src/lib/export/export-controller.ts`
- Test: `src/lib/export/export-controller.test.ts`

**Interfaces:**
- Consumes: `enumerateParts`/`PartJob`; a render-like client `{ render(req): Promise<RenderResult> }`; `fflate`.
- Produces:
  - `interface ExportProgress { done: number; total: number; current: string }`
  - `interface ExportedPart { name: string; stl: Uint8Array }`
  - `interface ExportResult { parts: ExportedPart[]; skipped: string[] }`
  - `async function renderParts(client, form, onProgress?): Promise<ExportResult>` — renders each `enumerateParts(form)` job sequentially at final quality; a job whose render throws the empty-STL error is added to `skipped` (NOT fatal); other errors propagate.
  - `function zipParts(parts: ExportedPart[]): Uint8Array` — `fflate.zipSync` of the parts by name.
  - `function isEmptyStlError(err: unknown): boolean` — matches the render core's degenerate-STL message.

- [ ] **Step 1: Install fflate**

```bash
cd ~/workspace/darkroomscad-web && npm install fflate
```

- [ ] **Step 2: Write the failing tests**

Create `src/lib/export/export-controller.test.ts`:

```ts
import { describe, it, expect, vi } from "vitest";
import { renderParts, zipParts } from "./export-controller";
import { unzipSync } from "fflate";
import type { RenderResult } from "../openscad/types";

const form = {
  Carrier_Type: "omega-d", Film_Format: "35mm", Orientation: "vertical",
  Text_As_Separate_Parts: false,
};
const ok = (stl: number[]): RenderResult => ({ stl: new Uint8Array(stl), log: "", durationMs: 1 });

describe("renderParts", () => {
  it("renders every part and reports progress", async () => {
    const render = vi.fn().mockResolvedValue(ok([1, 2, 3]));
    const seen: string[] = [];
    const result = await renderParts({ render }, form, (p) => seen.push(`${p.done}/${p.total}`));
    expect(render).toHaveBeenCalledTimes(2); // top + bottom
    expect(result.parts).toHaveLength(2);
    expect(result.skipped).toHaveLength(0);
    expect(seen[seen.length - 1]).toBe("2/2");
  });

  it("skips a part whose render is empty/degenerate (not fatal)", async () => {
    const render = vi.fn()
      .mockResolvedValueOnce(ok([1, 2, 3]))                                   // top OK
      .mockRejectedValueOnce(new Error("Render produced an empty (degenerate) STL.")); // bottom empty
    const result = await renderParts({ render }, form);
    expect(result.parts).toHaveLength(1);
    expect(result.skipped).toHaveLength(1);
  });

  it("propagates a non-empty render error (e.g. compile failure)", async () => {
    const render = vi.fn().mockRejectedValue(new Error("OpenSCAD exited with code 1."));
    await expect(renderParts({ render }, form)).rejects.toThrow(/code 1/);
  });
});

describe("zipParts", () => {
  it("bundles parts into a readable zip keyed by name", () => {
    const zip = zipParts([{ name: "a.stl", stl: new Uint8Array([1, 2]) }]);
    const back = unzipSync(zip);
    expect(Array.from(back["a.stl"])).toEqual([1, 2]);
  });
});
```

- [ ] **Step 3: Run to verify failure**

Run: `npm run test -- export-controller`
Expected: FAIL — not defined.

- [ ] **Step 4: Implement the controller**

Create `src/lib/export/export-controller.ts`:

```ts
import { zipSync } from "fflate";
import { enumerateParts } from "./part-enumeration";
import type { RenderParams, RenderResult } from "../openscad/types";

export interface ExportProgress { done: number; total: number; current: string }
export interface ExportedPart { name: string; stl: Uint8Array }
export interface ExportResult { parts: ExportedPart[]; skipped: string[] }

interface RenderLike {
  render(req: { params: RenderParams; quality: "preview" | "final" }): Promise<RenderResult>;
}

export function isEmptyStlError(err: unknown): boolean {
  return err instanceof Error && /empty \(degenerate\) STL|produced no output/i.test(err.message);
}

export async function renderParts(
  client: RenderLike,
  form: RenderParams,
  onProgress?: (p: ExportProgress) => void,
): Promise<ExportResult> {
  const jobs = enumerateParts(form);
  const parts: ExportedPart[] = [];
  const skipped: string[] = [];
  for (let i = 0; i < jobs.length; i++) {
    const job = jobs[i];
    onProgress?.({ done: i, total: jobs.length, current: job.name });
    try {
      const res = await client.render({ params: job.params, quality: "final" });
      parts.push({ name: job.name, stl: res.stl });
    } catch (err) {
      if (isEmptyStlError(err)) skipped.push(job.name);
      else throw err;
    }
  }
  onProgress?.({ done: jobs.length, total: jobs.length, current: "" });
  return { parts, skipped };
}

export function zipParts(parts: ExportedPart[]): Uint8Array {
  const entries: Record<string, Uint8Array> = {};
  for (const p of parts) entries[p.name] = p.stl;
  return zipSync(entries);
}
```

- [ ] **Step 5: Run to verify pass**

Run: `npm run test -- export-controller`
Expected: PASS.

- [ ] **Step 6: Commit**

```bash
git add package.json package-lock.json src/lib/export/export-controller.ts src/lib/export/export-controller.test.ts
git commit -m "feat(export): multi-part render controller with empty-skip + fflate zip"
```

---

### Task 3: Export panel UI + page integration (browser gate)

Replace the single "Download STL" bridge button with an export panel: **Download set (ZIP)** (default) and an individual-files mode. Browser-verified.

**Files:**
- Create: `src/components/ExportPanel.tsx`
- Modify: `src/app/page.tsx` (replace the download button with `<ExportPanel>`, wire the worker client + current params)

**Interfaces:**
- Consumes: `RenderClient`, `useCarrierForm().toParams`, `renderParts`/`zipParts`/`ExportProgress`.
- Produces: `ExportPanel({ client, getParams })` where `getParams(): RenderParams` returns the current full-quality form params (the page passes `() => toParams({})`).

- [ ] **Step 1: Build the export panel**

Create `src/components/ExportPanel.tsx`. Primary "Download set (ZIP)" + a disclosure for "Download individual files" that renders each part as it completes. Progress text from `onProgress`. Triggers downloads client-side.

```tsx
"use client";
import { useState } from "react";
import { renderParts, zipParts, type ExportProgress, type ExportedPart } from "@/lib/export/export-controller";
import type { RenderParams } from "@/lib/openscad/types";
import type { RenderClient } from "@/lib/openscad/client";

function download(name: string, data: Uint8Array, type: string) {
  const blob = new Blob([new Uint8Array(data)], { type });
  const url = URL.createObjectURL(blob);
  const a = document.createElement("a");
  a.href = url; a.download = name; a.click();
  URL.revokeObjectURL(url);
}

export function ExportPanel({ client, getParams }: {
  client: () => RenderClient;
  getParams: () => RenderParams;
}) {
  const [busy, setBusy] = useState(false);
  const [progress, setProgress] = useState<ExportProgress | null>(null);
  const [individual, setIndividual] = useState(false);
  const [parts, setParts] = useState<ExportedPart[]>([]);
  const [error, setError] = useState<string | null>(null);

  async function run(): Promise<ExportedPart[] | null> {
    setBusy(true); setError(null); setParts([]);
    try {
      const form = getParams();
      const result = await renderParts(client(), form, setProgress);
      setParts(result.parts);
      return result.parts;
    } catch (e) {
      setError((e as Error).message);
      return null;
    } finally {
      setBusy(false); setProgress(null);
    }
  }

  async function handleZip() {
    const p = await run();
    if (!p || p.length === 0) return;
    const form = getParams();
    const zipName = `${String(form.Carrier_Type)}_${String(form.Film_Format)}_carrier-set.zip`.replace(/\s+/g, "-");
    download(zipName, zipParts(p), "application/zip");
  }

  return (
    <div className="mt-6 space-y-2">
      <button onClick={handleZip} disabled={busy}
        className="w-full rounded px-4 py-2.5 font-medium"
        style={{ background: "var(--primary)", color: "#08120b", opacity: busy ? 0.6 : 1 }}>
        {busy ? (progress ? `Rendering ${progress.done}/${progress.total}…` : "Rendering…") : "Download set (ZIP)"}
      </button>

      <button onClick={() => setIndividual((v) => !v)} className="text-sm underline"
        style={{ color: "var(--secondary)" }}>
        {individual ? "Hide individual files" : "Download individual files"}
      </button>

      {individual && (
        <div className="space-y-1">
          <button onClick={() => run()} disabled={busy}
            className="w-full rounded px-3 py-1.5 text-sm"
            style={{ background: "var(--surface-muted)", color: "var(--text)", border: "1px solid var(--border)" }}>
            Render all parts
          </button>
          {parts.map((p) => (
            <button key={p.name} onClick={() => download(p.name, p.stl, "model/stl")}
              className="flex w-full items-center justify-between rounded px-3 py-1.5 text-sm"
              style={{ background: "var(--surface)", color: "var(--text-muted)", border: "1px solid var(--border)" }}>
              <span>{p.name}</span><span style={{ color: "var(--primary)" }}>Download</span>
            </button>
          ))}
        </div>
      )}

      {error && <p className="text-sm" style={{ color: "var(--error)" }}>Export error: {error}</p>}
    </div>
  );
}
```

- [ ] **Step 2: Wire it into the page**

In `src/app/page.tsx`, replace the existing single "Download STL" button (and `handleDownload`) with `<ExportPanel client={getClient} getParams={() => toParams({})} />`, where `getClient` lazily returns the `RenderClient` (reuse the existing `clientRef` accessor used for preview, so export and preview share one worker). Keep the preview/viewer/theme wiring intact.

- [ ] **Step 3: tsc + build**

Run: `npx tsc --noEmit` (clean) and `npm run build` (compiles). `npm run test` all green.

- [ ] **Step 4: Manual browser verification (the gate — controller runs this)**

Run `npm run dev`. Load the page. Verify:
1. **Download set (ZIP)**: renders top + bottom (progress "1/2", "2/2"), downloads a `<carrier>_<format>_carrier-set.zip`. Open it — it contains both STL files; open one in a viewer to confirm it's a valid carrier half.
2. Enable **Separate text parts (multi-material)** (Advanced) → the ZIP now contains Base + text parts per half, and any half with no text is **skipped** (not an empty STL).
3. **Download individual files** → "Render all parts" lists each part; each downloads individually.
4. An invalid config (if reachable) surfaces a readable export error, not a silent failure.
Capture a screenshot of the export panel mid-render and the resulting ZIP contents.

- [ ] **Step 5: Commit + push**

```bash
git add src/components/ExportPanel.tsx src/app/page.tsx
git commit -m "feat(export): export panel — ZIP set (default) + individual files; wire into page"
git push origin main
```

---

### Task 4: Deferred polish (slider units + no-flash hardening)

The two carried-forward Minors from Plan 3.

**Files:**
- Modify: `src/lib/form/types.ts`, `src/lib/form/form-model.ts`, `src/config/carrier-ui.ts`, `src/components/controls/Field.tsx` (slider units)
- Modify: `src/lib/theme/themes.ts` (or a generated snippet), `src/app/layout.tsx` (no-flash full vars)

**Interfaces:**
- `FieldConfig`/`ResolvedField` gain `unit?: string`; `resolveFormModel` passes it through; `Field` passes `field.unit` to `Slider`.

- [ ] **Step 1: Slider units**

Add `unit?: string` to `FieldConfig` and `ResolvedField` (`types.ts`); in `resolveFormModel` add `unit: fc.unit`; in `Field.tsx`'s `slider` case change `unit={undefined}` → `unit={field.unit}`. In `carrier-ui.ts`, add `unit: "mm"` to the dimensional sliders (`Custom_Film_Width/Height`, `Custom_Opening_Width/Height`, `TEXT_ETCH_DEPTH`, the four `*_Offset`, `Peg_Gap`, `Adjust_Film_Width/Height`, `Layer_Height_mm`) — NOT `Font_Size` (use `"pt"` or leave unitless per taste) or `Text_Layer_Multiple` (count). Add one form-model test asserting `unit` resolves from the overlay.

Run: `npm run test -- form-model` and confirm a slider shows its unit in the browser later.

- [ ] **Step 2: No-flash full-var hardening**

Make the inline `<head>` script in `layout.tsx` apply the FULL var set for the resolved theme before paint (not just `data-theme`), eliminating the brief flash for users with a persisted non-dark theme. Inline a minimal token table into the script as a JSON literal generated from `THEMES` (keep it in sync — e.g. import `THEMES` server-side and `JSON.stringify` the `{name: vars}` map into the script string). The script: read stored/`matchMedia` theme → set `data-theme` AND loop the theme's vars via `documentElement.style.setProperty`. `ThemeProvider`'s effect still runs (idempotent).

Run: `npm run build`; verify in the browser later (persisted light theme → no dark flash on reload).

- [ ] **Step 3: Verify + commit**

`npm run test` green, `npx tsc --noEmit` clean, `npm run build` compiles.

```bash
git add src/lib/form src/config/carrier-ui.ts src/components/controls/Field.tsx src/lib/theme/themes.ts src/app/layout.tsx
git commit -m "polish: slider units (mm) + full-var no-flash theme script"
```

---

### Task 5: Vercel deploy — GitHub-raw pinned source + deploy prep

Make the build self-sufficient on Vercel (no local DarkroomSCAD checkout) by fetching the carrier source from GitHub at a pinned ref, then prepare the Vercel deploy. **The actual deploy is USER-GATED — prepare and STOP.**

**Files:**
- Modify: `scripts/sync-scad.ts` (add a GitHub-raw fetch mode)
- Create: `scripts/scad-source.config.json` (the pinned ref) — or env `DARKROOMSCAD_REF`
- Modify: `README.md` (deploy notes)

**Interfaces:**
- `sync-scad.ts`: when no `--local <path>` is given AND `../DarkroomSCAD` is absent, fetch from GitHub: list `.scad` files under `negative-carriers/` via the GitHub trees API at the pinned ref, fetch each via `raw.githubusercontent.com`, then proceed exactly as the local path (write `public/scad/**`, parse the schema, write the manifest). The committed `public/scad/**` remains a fallback if the fetch fails (log + use existing).

- [ ] **Step 1: Add the GitHub-raw fetch mode to sync-scad.ts**

Pin the ref: create `scripts/scad-source.config.json`:
```json
{ "repo": "narrowstacks/DarkroomSCAD", "ref": "<PIN A COMMIT SHA HERE>", "subdir": "negative-carriers" }
```
(Record the current `main` SHA of `narrowstacks/DarkroomSCAD` — get it with `gh api repos/narrowstacks/DarkroomSCAD/commits/main --jq .sha`. Pin the SHA, not `main`, for reproducible builds.)

In `resolveSource()` / `main()`: if `--local` is absent and `../DarkroomSCAD/negative-carriers/carrier.scad` does not exist, switch to GitHub mode:
- `GET https://api.github.com/repos/<repo>/git/trees/<ref>?recursive=1` → filter paths under `<subdir>/` ending in `.scad`.
- For each, `GET https://raw.githubusercontent.com/<repo>/<ref>/<path>` → write to `public/scad/<path-relative-to-subdir>`.
- Parse `carrier.scad` → schema; write manifest (same as local mode).
- On any fetch error: `console.warn` and fall back to the already-committed `public/scad/**` (do NOT throw — Vercel build must not fail on a transient GitHub hiccup when usable artifacts exist).

Keep `collectScadFiles` + the local path mode unchanged (dev still uses `--local ../DarkroomSCAD`). Add a unit test for the GitHub path-filtering helper (pure: given a trees-API response, returns the `.scad` paths under the subdir) — do NOT hit the network in tests.

- [ ] **Step 2: Verify the build is self-sufficient**

From a state where `../DarkroomSCAD` is reachable, `npm run sync:scad` still works (local mode). Then simulate CI: temporarily rename/point away from the local source and run `npm run sync:scad` — it fetches from GitHub at the pinned ref and writes `public/scad/**` + the schema + manifest. Confirm `npm run build` succeeds end-to-end. Run `npm run test` (incl. the new path-filter test) green; `npx tsc --noEmit` clean.

- [ ] **Step 3: Prepare the Vercel deploy (do NOT deploy yet)**

- Confirm `next.config.ts`'s COOP/COEP headers are present (the WASM worker needs cross-origin isolation) — these apply on Vercel via Next headers.
- Confirm the build outputs a static-servable app (no serverless functions required); the 9.6MB `openscad.wasm` + assets are static `public/` files Vercel serves directly.
- Add deploy notes to `README.md`: the pinned-ref source model, the COOP/COEP requirement, and how to bump the source ref.
- Commit the deploy-readiness changes and push.
- **STOP and hand off to the controller/user for the actual deploy.** Report that the project is deploy-ready and what the deploy command will be (`vercel` / the Vercel deploy flow), noting it publishes the site and needs the user's go-ahead.

```bash
git add scripts/sync-scad.ts scripts/scad-source.config.json README.md
git commit -m "feat(build): GitHub-raw pinned-ref source fetch for CI/Vercel; deploy readiness"
git push origin main
```

- [ ] **Step 4: (Controller/user-gated) Deploy to Vercel + smoke test**

After user confirmation: deploy via Vercel (CLI `vercel` or the Vercel deploy flow), set any needed config, and smoke-test the production URL:
1. The page loads; the customizer renders.
2. A preview render completes (WASM works behind the COOP/COEP headers on Vercel).
3. The export ZIP downloads.
If the production WASM render fails on headers, verify the COOP/COEP response headers are actually present on the deployed `/wasm/*` and document the fix.

---

## Plan 4 Self-Review

- **Spec coverage:** complete-set export as ZIP (default) OR individual files, user's choice (Tasks 1-3) ✓; part enumeration incl. multi-material text parts, alignment board as in-geometry, empty-part skipping (Tasks 1-2) ✓; meaningful filenames (Task 1) ✓; the Plan 3 deferred polish — slider units + no-flash hardening (Task 4) ✓; Vercel deploy with the spec's GitHub-raw pinned-ref source model + the `prebuild` CI fix (Task 5) ✓; deploy is user-gated (Global Constraints + Task 5 Step 3) ✓.
- **Placeholder scan:** complete code for the testable logic (enumeration, controller, zip). The two genuine unknowns are honestly handled, not hand-waved: (a) which half(s) carry text is resolved at runtime by **skipping empty renders** (Task 2) rather than guessing the SCAD; (b) the pinned source SHA is a literal the implementer fills from `gh api` (Task 5 Step 1).
- **Type consistency:** `PartJob` (Task 1) consumed by `renderParts` (Task 2). `ExportedPart`/`ExportProgress`/`ExportResult` defined in Task 2, consumed by `ExportPanel` (Task 3). Reuses Plan 1 `RenderParams`/`RenderResult`/`RenderClient` and Plan 2 `toParams` unchanged. `unit?` added once to the form types (Task 4) and threaded through resolver→Field→Slider.

## Notes for the executor

- **Empty-part skipping is load-bearing**, not an optimization: the carrier likely etches text on only one face, so `OwnerText`/`TypeText` for the other half render empty. The controller catches the render core's degenerate-STL error per part and skips it; only a *non-empty* error (compile failure) aborts the export. Verify the skip path in the browser by enabling multi-material text.
- **Export shares the preview worker.** Don't spin up a second worker for export — reuse the page's `RenderClient` (the worker serializes renders, so export jobs queue behind any in-flight preview). Full-quality export renders are slower (~seconds each); the progress UI covers that.
- **Pin the source SHA, not `main`.** A moving `main` makes Vercel builds non-reproducible and can silently change the deployed carrier. Bumping the carrier design = update the SHA in `scad-source.config.json` deliberately.
- **Deploy publishes the site.** Do not run the actual Vercel deploy without the user's explicit go-ahead.

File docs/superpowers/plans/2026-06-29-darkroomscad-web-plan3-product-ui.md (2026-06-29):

# DarkroomSCAD Web — Plan 3: Product UI (Friendly Controls + Theming)

> **For agentic workers:** REQUIRED SUB-SKILL: Use superpowers:subagent-driven-development (recommended) or superpowers:executing-plans to implement this plan task-by-task. Steps use checkbox (`- [ ]`) syntax for tracking.

**Goal:** Reshape the customizer from an OpenSCAD-customizer port (dropdowns, checkboxes, number fields) into a friendly web product — segmented buttons, toggle switches, sliders, enlarger cards, and a signature **film-format picker** whose chips show each format's true frame proportions — and add a full theme system (dark / light / darkroom-safelight / high-contrast) with a toggle.

**Architecture:** Extend the Plan 2 control model with new control kinds and a small kit of presentational components; add one bespoke `FilmFormatPicker` for the signature. The curation overlay (`carrier-ui.ts`) is rewritten to assign each field a friendly control. A theme system stores tokens as TS objects (single source of truth), applies them as CSS custom properties, and exposes 3D-viewer colors to the viewer so it follows the theme. No change to the render pipeline (Plan 1) or the form-state/preview contracts (Plan 2).

**Tech Stack:** Next.js 15 (App Router), React 19, Tailwind v4, TypeScript, Vitest. Builds on Plan 1 (Manifold WASM render core) + Plan 2 (schema-driven form, preview controller, r3f viewer).

## Global Constraints

- **Repo:** all work in `~/workspace/darkroomscad-web` (`main`, remote `origin` = github.com/narrowstacks/darkroomscad-web). Push at the end of each task that the plan says to push.
- **No backend.** Client-side WASM only; app stays effectively static.
- **Reuse Plan 1/2; don't fork.** Consume `resolveFormModel`/`ResolvedField`/`ControlKind` (`src/lib/form/`), `useCarrierForm`, `PreviewController`, `RenderClient`, `StlViewer`, `parseBinaryStl`, `generated/param-schema.json`, `BUNDLED_FONTS`. Do NOT change `render.ts`/`worker.ts` render args or the worker protocol.
- **Schema is the source of truth.** Every control still binds to a real schema param; the overlay consistency test (`carrier-ui.test.ts`) must keep passing. The `FilmFormatPicker` may only ever produce `Film_Format` values that exist in the schema's enum — guard this with a test.
- **`Render_Quality` stays system-managed** (preview vs final); never a user control.
- **Visual language (dorkroom-aligned):** Fraunces (display) + Montserrat (UI); numeric readouts use `font-variant-numeric: tabular-nums`. Accent semantics unchanged: primary = mint `#6ef3a4`, error = coral `#f99f96`.
- **Themes (exact token sets in Task 4):** `dark` (default), `light`, `darkroom` (red-on-black safelight), `high-contrast`. Theme persists in `localStorage` (`darkroomscad-theme`); initial theme respects `prefers-color-scheme` when unset. No flash of wrong theme on load.
- **Deferred to Plan 4 (do NOT build here):** ZIP / multi-part export + part enumeration; Vercel deploy + the `prebuild` CI fix (GitHub-raw pinned fetch). Plan 3 keeps the single-STL "Download" button from Plan 2.
- **Accessibility floor:** every control keyboard-operable with a visible focus ring; toggles use `role="switch"`/`aria-checked`; segmented groups use real `<button>`s with `aria-pressed`; sliders are native `<input type=range>` with a visible value; respect `prefers-reduced-motion`.

## Design Direction (the signature)

- **Film-format chips** are the page's memorable element: each chip draws a frame at the format's true aspect ratio (35mm 3:2, 6×6 1:1, 6×7 5:4, 4×5 5:4, …) so the control *looks like the thing it selects*. The 16 raw schema formats collapse to ~8 base chips + a **"filed edges"** toggle (maps `X` → `X filed`) + a **Custom** chip that reveals the dimension sliders. This is one place to spend boldness; keep all other controls quiet.
- **Enlarger cards** carry the second on-subject visual: each card shows an SVG **silhouette of that carrier's general outline** (outer body only, no film opening), generated from the real geometry. Two quiet, accurate glyphs — the film frame and the carrier body — not decoration.
- Everything else is a disciplined control kit: **segmented** button groups (orientation, part, pegs, board type, type-label source), **switches** (etch name, etch type, alignment board, flip, separate text parts), **sliders** (font size, offsets, gaps, dimensions), **cards** (enlarger).

---

### Task 1: Control-kit primitives (Segmented, Switch, Slider, CardSelect)

Add the friendly controls and wire `Field` to dispatch to them. Value-coercion logic is TDD'd; the visuals are browser-verified in Task 5.

**Files:**
- Modify: `src/lib/form/types.ts` (extend `ControlKind`)
- Create: `src/lib/form/control-value.ts` (shared option-value coercion + slider clamp)
- Test: `src/lib/form/control-value.test.ts`
- Create: `src/components/controls/Segmented.tsx`, `Switch.tsx`, `Slider.tsx`, `CardSelect.tsx`
- Modify: `src/components/controls/Field.tsx` (dispatch to the new kinds)

**Interfaces:**
- Produces:
  - `type ControlKind = "select" | "number" | "text" | "toggle" | "segmented" | "switch" | "slider" | "cards"`
  - `function coerceOptionValue(options: { value: string | number; label: string }[] | undefined, raw: string): string | number` — maps a selected control's string back to the typed option value (numbers stay numbers).
  - `function clampSlider(value: number, min?: number, max?: number): number`
  - `Segmented(props: { options; value; onChange; label; ariaLabel })`, `Switch(props: { checked; onChange; label; help? })`, `Slider(props: { value; min?; max?; step?; onChange; label; unit? })`, `CardSelect(props: { options; value; onChange; label })`

- [ ] **Step 1: Write the failing test for control-value helpers**

Create `src/lib/form/control-value.test.ts`:

```ts
import { describe, it, expect } from "vitest";
import { coerceOptionValue, clampSlider } from "./control-value";

describe("coerceOptionValue", () => {
  it("returns the typed (number) value for a matching numeric option", () => {
    const opts = [{ value: 1, label: "One" }, { value: 2, label: "Two" }];
    expect(coerceOptionValue(opts, "2")).toBe(2);
    expect(typeof coerceOptionValue(opts, "2")).toBe("number");
  });
  it("returns the string value for a matching string option", () => {
    const opts = [{ value: "omega-d", label: "Omega" }];
    expect(coerceOptionValue(opts, "omega-d")).toBe("omega-d");
  });
  it("falls back to the raw string when there are no options", () => {
    expect(coerceOptionValue(undefined, "x")).toBe("x");
  });
});

describe("clampSlider", () => {
  it("clamps to min and max when provided", () => {
    expect(clampSlider(5, 0, 10)).toBe(5);
    expect(clampSlider(-3, 0, 10)).toBe(0);
    expect(clampSlider(99, 0, 10)).toBe(10);
  });
  it("passes through when bounds are absent", () => {
    expect(clampSlider(42)).toBe(42);
  });
});
```

- [ ] **Step 2: Run to verify failure**

Run: `npm run test -- control-value`
Expected: FAIL — not defined.

- [ ] **Step 3: Implement the helpers + extend ControlKind**

In `src/lib/form/types.ts`, replace the `ControlKind` definition with:

```ts
export type ControlKind =
  | "select" | "number" | "text" | "toggle"
  | "segmented" | "switch" | "slider" | "cards";
```

Create `src/lib/form/control-value.ts`:

```ts
export function coerceOptionValue(
  options: { value: string | number; label: string }[] | undefined,
  raw: string,
): string | number {
  const opt = options?.find((o) => String(o.value) === raw);
  return opt ? opt.value : raw;
}

export function clampSlider(value: number, min?: number, max?: number): number {
  let v = value;
  if (min !== undefined && v < min) v = min;
  if (max !== undefined && v > max) v = max;
  return v;
}
```

- [ ] **Step 4: Run to verify pass**

Run: `npm run test -- control-value`
Expected: PASS.

- [ ] **Step 5: Build the four primitives**

Create `src/components/controls/Segmented.tsx`:

```tsx
"use client";
import { coerceOptionValue } from "@/lib/form/control-value";
import type { FormValue } from "@/lib/form/types";

export function Segmented({ options, value, onChange, label, ariaLabel }: {
  options: { value: string | number; label: string }[];
  value: FormValue;
  onChange: (v: FormValue) => void;
  label: string;
  ariaLabel?: string;
}) {
  return (
    <div className="py-1">
      <span className="block text-sm font-medium mb-1" style={{ color: "var(--text)" }}>{label}</span>
      <div role="group" aria-label={ariaLabel ?? label}
        className="inline-flex flex-wrap gap-1 rounded-lg p-1"
        style={{ background: "var(--surface-muted)", border: "1px solid var(--border)" }}>
        {options.map((o) => {
          const selected = String(o.value) === String(value);
          return (
            <button key={String(o.value)} type="button" aria-pressed={selected}
              onClick={() => onChange(coerceOptionValue(options, String(o.value)))}
              className="rounded-md px-3 py-1.5 text-sm transition-colors focus-visible:outline-2"
              style={selected
                ? { background: "var(--primary)", color: "#08120b", fontWeight: 600 }
                : { color: "var(--text-muted)" }}>
              {o.label}
            </button>
          );
        })}
      </div>
    </div>
  );
}
```

Create `src/components/controls/Switch.tsx`:

```tsx
"use client";

export function Switch({ checked, onChange, label, help }: {
  checked: boolean;
  onChange: (v: boolean) => void;
  label: string;
  help?: string;
}) {
  return (
    <div className="flex items-center justify-between gap-3 py-1.5">
      <div>
        <span className="text-sm font-medium" style={{ color: "var(--text)" }}>{label}</span>
        {help && <p className="text-xs" style={{ color: "var(--text-dim)" }}>{help}</p>}
      </div>
      <button type="button" role="switch" aria-checked={checked} aria-label={label}
        onClick={() => onChange(!checked)}
        className="relative h-6 w-11 shrink-0 rounded-full transition-colors focus-visible:outline-2"
        style={{ background: checked ? "var(--primary)" : "var(--surface-muted)", border: "1px solid var(--border)" }}>
        <span className="absolute top-0.5 h-4 w-4 rounded-full transition-all"
          style={{ left: checked ? "1.5rem" : "0.15rem", background: checked ? "#08120b" : "var(--text-muted)" }} />
      </button>
    </div>
  );
}
```

Create `src/components/controls/Slider.tsx`:

```tsx
"use client";
import { clampSlider } from "@/lib/form/control-value";

export function Slider({ value, min, max, step, onChange, label, unit }: {
  value: number;
  min?: number;
  max?: number;
  step?: number;
  onChange: (v: number) => void;
  label: string;
  unit?: string;
}) {
  return (
    <div className="py-1.5">
      <div className="flex items-baseline justify-between">
        <label className="text-sm font-medium" style={{ color: "var(--text)" }}>{label}</label>
        <span className="text-sm tabular-nums" style={{ color: "var(--text-muted)" }}>
          {value}{unit ? ` ${unit}` : ""}
        </span>
      </div>
      <input type="range" value={value}
        min={min ?? 0} max={max ?? 100} step={step ?? 1}
        onChange={(e) => onChange(clampSlider(Number(e.target.value), min, max))}
        className="mt-1 w-full accent-[var(--primary)]" style={{ accentColor: "var(--primary)" }} />
    </div>
  );
}
```

Create `src/components/controls/CardSelect.tsx`:

```tsx
"use client";
import { coerceOptionValue } from "@/lib/form/control-value";
import type { FormValue } from "@/lib/form/types";

export function CardSelect({ options, value, onChange, label }: {
  options: { value: string | number; label: string }[];
  value: FormValue;
  onChange: (v: FormValue) => void;
  label: string;
}) {
  return (
    <div className="py-1">
      <span className="block text-sm font-medium mb-1.5" style={{ color: "var(--text)" }}>{label}</span>
      <div className="grid grid-cols-2 gap-2">
        {options.map((o) => {
          const selected = String(o.value) === String(value);
          return (
            <button key={String(o.value)} type="button" aria-pressed={selected}
              onClick={() => onChange(coerceOptionValue(options, String(o.value)))}
              className="rounded-lg px-3 py-2.5 text-sm text-left transition-colors focus-visible:outline-2"
              style={{
                background: selected ? "var(--surface-muted)" : "var(--surface)",
                border: `1px solid ${selected ? "var(--primary)" : "var(--border)"}`,
                color: selected ? "var(--text)" : "var(--text-muted)",
              }}>
              {o.label}
            </button>
          );
        })}
      </div>
    </div>
  );
}
```

- [ ] **Step 6: Dispatch from Field**

Replace `src/components/controls/Field.tsx`'s control switch so it routes the new kinds (keep the existing select/number/text/toggle for fallback). The new file:

```tsx
"use client";
import type { ResolvedField, FormValue } from "@/lib/form/types";
import { Segmented } from "./Segmented";
import { Switch } from "./Switch";
import { Slider } from "./Slider";
import { CardSelect } from "./CardSelect";
import { coerceOptionValue } from "@/lib/form/control-value";

export function Field({ field, value, onChange }: {
  field: ResolvedField;
  value: FormValue;
  onChange: (v: FormValue) => void;
}) {
  switch (field.control) {
    case "segmented":
      return <Segmented options={field.options ?? []} value={value} onChange={onChange} label={field.label} />;
    case "cards":
      return <CardSelect options={field.options ?? []} value={value} onChange={onChange} label={field.label} />;
    case "switch":
    case "toggle":
      return <Switch checked={value === true} onChange={onChange} label={field.label} help={field.help} />;
    case "slider":
      return <Slider value={Number(value)} min={field.min} max={field.max} step={field.step}
        onChange={onChange} label={field.label} unit={undefined} />;
    case "select":
      return (
        <div className="py-1">
          <label className="block text-sm font-medium" style={{ color: "var(--text)" }}>{field.label}</label>
          <select value={String(value)} onChange={(e) => onChange(coerceOptionValue(field.options, e.target.value))}
            className="mt-1 w-full rounded px-2 py-1.5 text-sm"
            style={{ background: "var(--surface-muted)", color: "var(--text)", border: "1px solid var(--border)" }}>
            {field.options?.map((o) => <option key={String(o.value)} value={String(o.value)}>{o.label}</option>)}
          </select>
        </div>
      );
    case "number":
      return (
        <div className="py-1">
          <label className="block text-sm font-medium" style={{ color: "var(--text)" }}>{field.label}</label>
          <input type="number" value={Number(value)} min={field.min} max={field.max} step={field.step ?? "any"}
            onChange={(e) => onChange(e.target.value === "" ? 0 : Number(e.target.value))}
            className="mt-1 w-full rounded px-2 py-1.5 text-sm"
            style={{ background: "var(--surface-muted)", color: "var(--text)", border: "1px solid var(--border)" }} />
        </div>
      );
    default:
      return (
        <div className="py-1">
          <label className="block text-sm font-medium" style={{ color: "var(--text)" }}>{field.label}</label>
          <input type="text" value={String(value)} onChange={(e) => onChange(e.target.value)}
            className="mt-1 w-full rounded px-2 py-1.5 text-sm"
            style={{ background: "var(--surface-muted)", color: "var(--text)", border: "1px solid var(--border)" }} />
        </div>
      );
  }
}
```

- [ ] **Step 7: Suite + build**

Run: `npm run test` (control-value + all prior green).
Run: `npx tsc --noEmit` (clean) and `npm run build` (compiles).

- [ ] **Step 8: Commit**

```bash
git add src/lib/form/types.ts src/lib/form/control-value.ts src/lib/form/control-value.test.ts src/components/controls
git commit -m "feat(ui): control-kit primitives (segmented, switch, slider, cards) + Field dispatch"
```

---
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

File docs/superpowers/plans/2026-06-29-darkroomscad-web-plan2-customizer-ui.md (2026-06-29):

# DarkroomSCAD Web — Plan 2: Guided Customizer UI & Live Preview

> **For agentic workers:** REQUIRED SUB-SKILL: Use superpowers:subagent-driven-development (recommended) or superpowers:executing-plans to implement this plan task-by-task. Steps use checkbox (`- [ ]`) syntax for tracking.

**Goal:** Turn the Plan 1 render core into a guided, no-code customizer: photographers pick options from clean form controls (auto-generated from the carrier's parameter schema), see a live 3D preview that updates as they change parameters, and download an STL.

**Architecture:** A hand-maintained **curation overlay** (`carrier-ui.ts`) maps the generated `param-schema.json` into user-facing groups/fields with labels, help, conditional visibility, and an "Advanced" tier. A pure form-state layer produces `RenderParams`; a **preview controller** debounces changes and coalesces to the latest render (drop-stale, newest-wins) via the Plan 1 `RenderClient`; a **react-three-fiber** viewer shows the resulting STL. Baseline dorkroom-aligned dark styling (full multi-theme system is Plan 3).

**Tech Stack:** Next.js 15 (App Router) + TypeScript, React 19, Tailwind CSS v4, `three` + `@react-three/fiber` + `@react-three/drei`, Vitest. Engine: vendored OpenSCAD 2025.03.25 WASM (Manifold).

## Global Constraints

- **Repo:** all work in `~/workspace/darkroomscad-web` (Plan 1 complete, on `main`, remote `origin` = github.com/narrowstacks/darkroomscad-web).
- **No backend.** All rendering stays client-side WASM in the Plan 1 Web Worker. The app stays effectively static.
- **Reuse Plan 1, don't fork it.** Consume `RenderClient` (`src/lib/openscad/client.ts`), `RenderRequest`/`RenderResult`/`RenderParams`/`RenderQuality` (`src/lib/openscad/types.ts`), `parseCustomizer`/`Param`/`ParamSchema` (`src/lib/params/`), `generated/param-schema.json`, and `BUNDLED_FONTS`/`DEFAULT_FONT_FAMILY` (`src/config/fonts.ts`). Do not change `render.ts` render args or `worker.ts` protocol.
- **Engine quality control:** preview renders set the **`Render_Quality` param to `"preview"`** (carrier.scad maps that to `$fn=32`, faster); the download sets `Render_Quality="final"` (`$fn=100`). `Render_Quality` is **system-managed and hidden from the form**.
- **Fonts:** the `Fontface` control is a dropdown sourced from `BUNDLED_FONTS` (currently just `Liberation Mono`); default is `DEFAULT_FONT_FAMILY`. Never a free-text font field (only bundled fonts render).
- **Proprietary font default:** the schema's `Fontface` default (`Lucida Console`) must be overridden to `DEFAULT_FONT_FAMILY` in the form's initial values.
- **Visual language (dorkroom-aligned, baseline only this plan):** Fraunces (display/headings) + Montserrat (UI/body); dark surface palette — bg `#09090b`, surfaces `#121214`/`#1c1c1f`, accents mint `#6ef3a4` (primary), sky `#7dd6ff`, coral `#f99f96`, lime `#e5ff7d`; text `#ffffff`→`#a1a1aa`→`#71717a`; borders `rgba(255,255,255,0.1)`. Viewer materials: model `#9a9a9a`, grid/edges `#353535`. Semantic: error = coral, success = mint. (Full theme toggle + light/safelight/high-contrast = Plan 3.)
- **Deferred to Plan 3 (do NOT build here):** ZIP / multi-part export + part enumeration; full theme system & toggle; comprehensive error-UX surfaces; Vercel deploy + the `prebuild` CI fix. Plan 2 ships a single-STL "Download" bridge button (current part, full quality).

---

### Task 1: 3D/UI dependencies + dorkroom base theme

Foundational setup the viewer and page depend on. No new logic; deliverable verified by build + a visible themed page.

**Files:**
- Modify: `package.json` (add `three`, `@react-three/fiber`, `@react-three/drei`, `@types/three`)
- Create: `src/app/theme.css` (CSS custom properties — the dorkroom dark tokens)
- Modify: `src/app/globals.css` (import theme.css; base body styles)
- Modify: `src/app/layout.tsx` (load Fraunces + Montserrat via `next/font/google`; apply font CSS vars)

**Interfaces:**
- Produces: CSS variables `--bg`, `--surface`, `--surface-muted`, `--border`, `--text`, `--text-muted`, `--text-dim`, `--primary`, `--secondary`, `--accent`, `--highlight`, `--error`, `--viewer-model`, `--viewer-grid`; font vars `--font-display`, `--font-sans`.

- [ ] **Step 1: Install dependencies**

```bash
cd ~/workspace/darkroomscad-web
npm install three @react-three/fiber @react-three/drei
npm install -D @types/three
```

- [ ] **Step 2: Create the theme tokens**

Create `src/app/theme.css`:

```css
:root {
  --bg: #09090b;
  --surface: #121214;
  --surface-muted: #1c1c1f;
  --border: rgba(255, 255, 255, 0.1);
  --border-strong: rgba(255, 255, 255, 0.2);
  --text: #ffffff;
  --text-muted: #a1a1aa;
  --text-dim: #71717a;
  --primary: #6ef3a4;
  --secondary: #7dd6ff;
  --accent: #f99f96;
  --highlight: #e5ff7d;
  --error: #f99f96;
  --success: #6ef3a4;
  --viewer-model: #9a9a9a;
  --viewer-grid: #353535;
}
```

- [ ] **Step 3: Wire fonts + globals**

Replace `src/app/layout.tsx` with (keeps Next metadata, adds the two Google fonts as CSS vars):

```tsx
import type { Metadata } from "next";
import { Fraunces, Montserrat } from "next/font/google";
import "./globals.css";

const fraunces = Fraunces({ subsets: ["latin"], variable: "--font-display", display: "swap" });
const montserrat = Montserrat({ subsets: ["latin"], variable: "--font-sans", display: "swap" });

export const metadata: Metadata = {
  title: "DarkroomSCAD — Negative Carrier Customizer",
  description: "Configure and export 3D-printable darkroom negative carriers, rendered in your browser.",
};

export default function RootLayout({ children }: { children: React.ReactNode }) {
  return (
    <html lang="en" className={`${fraunces.variable} ${montserrat.variable}`}>
      <body>{children}</body>
    </html>
  );
}
```

Replace `src/app/globals.css` with:

```css
@import "tailwindcss";
@import "./theme.css";

body {
  background: var(--bg);
  color: var(--text);
  font-family: var(--font-sans), ui-sans-serif, system-ui, sans-serif;
}

h1, h2, h3 {
  font-family: var(--font-display), Georgia, serif;
}
```

- [ ] **Step 4: Verify build + a themed page renders**

Run: `npm run build`
Expected: compiles successfully, no errors.
Run: `npm run dev` then load the page — body is near-black `#09090b`, headings use a serif. (The page content is still the Plan 1 render-core button; that's replaced in Task 6.)

- [ ] **Step 5: Commit**

```bash
git add package.json package-lock.json src/app/theme.css src/app/globals.css src/app/layout.tsx
git commit -m "feat(ui): add three/r3f/drei deps and dorkroom dark theme tokens + fonts"
```

---
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

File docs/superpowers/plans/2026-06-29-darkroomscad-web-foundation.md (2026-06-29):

# DarkroomSCAD Web — Plan 1: Foundation & Render Core

> **For agentic workers:** REQUIRED SUB-SKILL: Use superpowers:subagent-driven-development (recommended) or superpowers:executing-plans to implement this plan task-by-task. Steps use checkbox (`- [ ]`) syntax for tracking.

**Goal:** Stand up the `darkroomscad-web` repo and a working client-side slice that renders the default DarkroomSCAD carrier to an STL in the browser via WASM and downloads it — proving `textmetrics`, BOSL2, and fonts work end-to-end.

**Architecture:** Next.js (App Router) static app on Vercel. A build-time script syncs `.scad` source from the DarkroomSCAD repo and parses its customizer annotations into a JSON schema. OpenSCAD runs entirely in the browser inside a Web Worker (`openscad-wasm`, Manifold backend), with BOSL2 + bundled fonts mounted into its virtual filesystem. Plan 1 stops at a single hard-coded render-and-download path; the guided UI (Plan 2) and export/theming (Plan 3) build on this core.
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

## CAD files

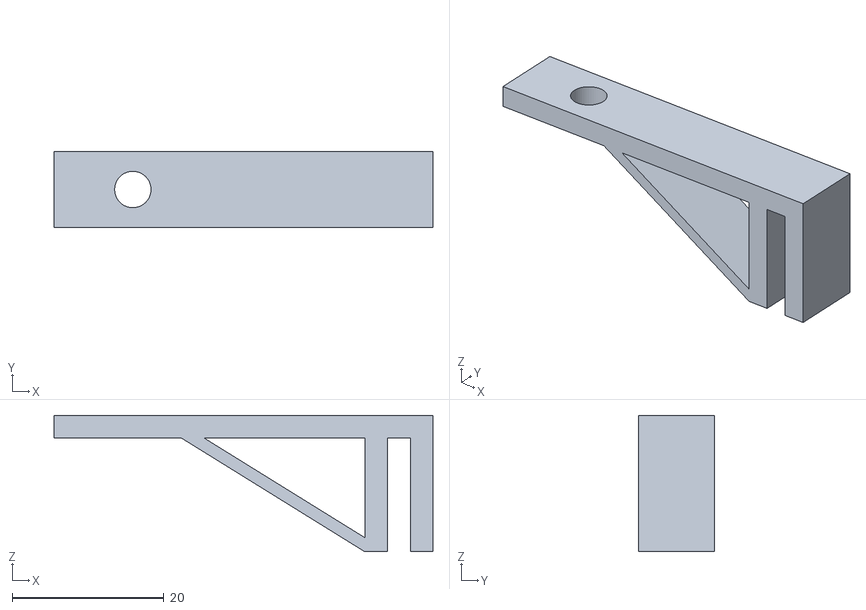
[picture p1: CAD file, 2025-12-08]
development-tools/thermometer-holder.stl
50.0 x 10.0 x 18.0

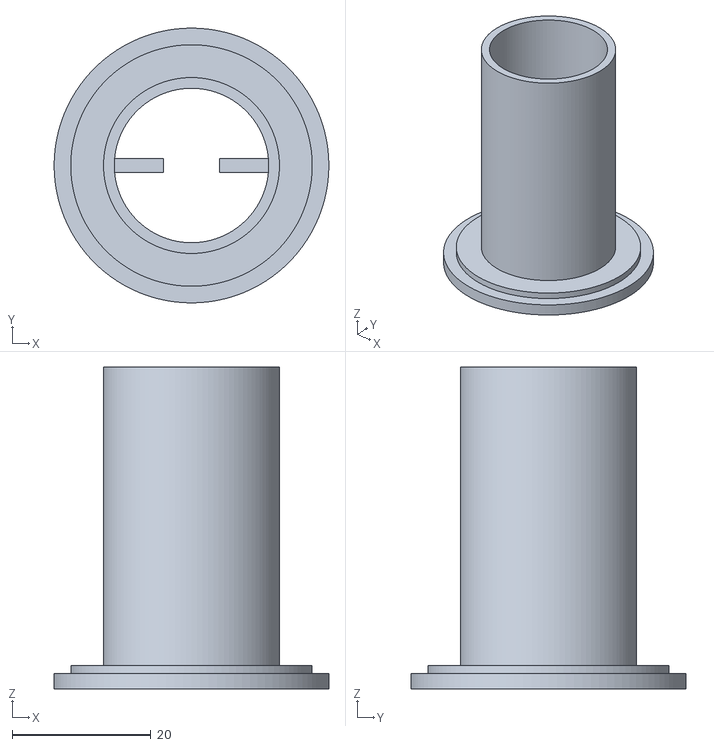
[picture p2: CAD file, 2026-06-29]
patterson-tank/1-reel-tube.stl
39.6 x 39.6 x 46.4

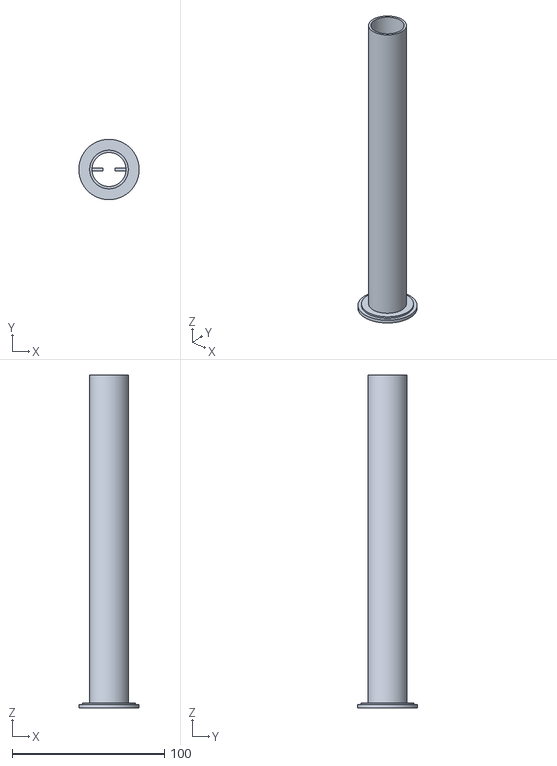
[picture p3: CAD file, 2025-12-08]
patterson-tank/5-reel-tube.stl
39.6 x 39.6 x 218.4

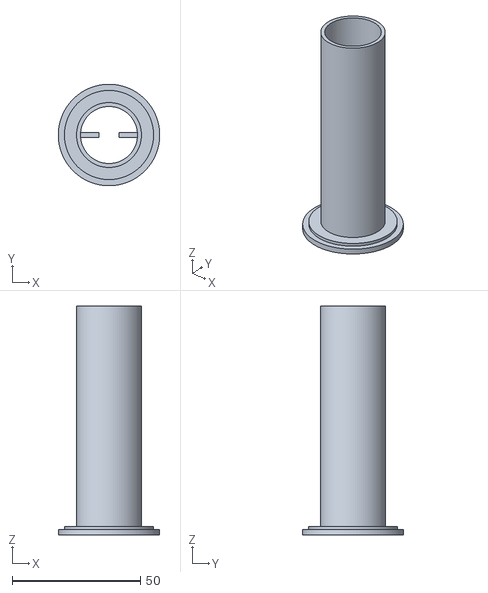
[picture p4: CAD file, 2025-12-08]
patterson-tank/2-reel-tube.stl
39.6 x 39.6 x 89.4

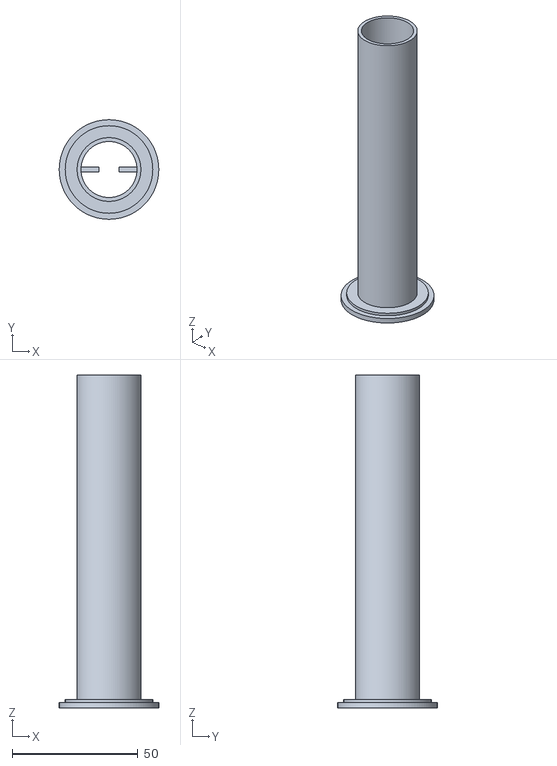
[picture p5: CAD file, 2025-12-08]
patterson-tank/3-reel-tube.stl
39.6 x 39.6 x 132.4

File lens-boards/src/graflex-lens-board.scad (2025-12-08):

include <common/lens-sizes.scad>

/* [Lens Settings] */
// Select lens mount type
Lens_Type = "Copal 0"; // ["Copal 0", "Copal 1", "Copal 3"]

/* [Hidden] */
$fn = 100;
LENS_BOARD_WIDTH = 93.66;
LENS_BOARD_LENGTH = 92.07;

// Get lens dimensions from lookup table
_lens_dims = get_lens_format(Lens_Type);
_lens_mount_diameter = _lens_dims[0];
_lens_mount_thickness = _lens_dims[1];

module graflex_lens_board(mount_diameter, board_thickness) {
    difference() {
        cube([LENS_BOARD_WIDTH, LENS_BOARD_LENGTH, board_thickness], center=true);
        cylinder(h=board_thickness + 0.1, d=mount_diameter, center=true);
    }
}

graflex_lens_board(_lens_mount_diameter, _lens_mount_thickness);

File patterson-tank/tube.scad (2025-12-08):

/* Setup parameters */
// The number of 35mm reels to fit in the tube. Rule of thumb: 1 medium format reel = ~1.5 35mm reels (round up to 2).
Number_Of_Reels = 2;

/* [Hidden] */
$fn = 100;

THIRTYFIVEMM_REEL_HEIGHT = 42;
TUBE_LENGTH = 43 * Number_Of_Reels;
TUBE_THICKNESS = 1.55;
TUBE_OUTER_DIAMETER = 25.35;
TUBE_INNER_DIAMETER = TUBE_OUTER_DIAMETER - TUBE_THICKNESS * 2;
BASE_HEIGHT_LOWER = 2.2;
BASE_HEIGHT_HIGHER = 3.4 - BASE_HEIGHT_LOWER;
BASE_LOWER_DIAMETER = 39.6;
BASE_HIGHER_DIAMETER = 34.8;
INNER_BOTTOM_CUTOUT_DIAMETER = 30;
ROTARY_STICK_HOLDER_LENGTH = (TUBE_INNER_DIAMETER - 8) / 2;
ROTARY_STICK_HOLDER_WIDTH = 2;
ROTARY_STICK_HOLDER_HEIGHT = 15;

module tube(length, outer_diameter, inner_diameter, thickness) {
    total_base_height = BASE_HEIGHT_LOWER + BASE_HEIGHT_HIGHER;

    union() {
        difference() {
            union() {
                // Main tube positioned so it starts at top of bases
                translate([0, 0, total_base_height + length / 2]) cylinder(h=length, d=outer_diameter, center=true, $fn=100);
                // Lower base at z=0
                cylinder(h=BASE_HEIGHT_LOWER, d=BASE_LOWER_DIAMETER, $fn=100);
                // Higher base on top of lower base
                translate([0, 0, BASE_HEIGHT_LOWER]) cylinder(h=BASE_HEIGHT_HIGHER, d=BASE_HIGHER_DIAMETER, $fn=100);
            }
            // Inner cutout for entire tube length plus bases
            cylinder(h=total_base_height + length, d=inner_diameter, $fn=100);
            // Bottom cutout
            cylinder(h=BASE_HEIGHT_LOWER / 2, d=INNER_BOTTOM_CUTOUT_DIAMETER, $fn=100);
        }

        // Rotary stick holders - two opposite each other inside the tube near the top
        for (angle = [0, 180]) {
            rotate([0, 0, angle])
                translate([inner_diameter / 2 - ROTARY_STICK_HOLDER_LENGTH, -ROTARY_STICK_HOLDER_WIDTH / 2, total_base_height + length - 15 - ROTARY_STICK_HOLDER_HEIGHT])
                    cube([ROTARY_STICK_HOLDER_LENGTH, ROTARY_STICK_HOLDER_WIDTH, ROTARY_STICK_HOLDER_HEIGHT]);
        }
    }
}

tube(TUBE_LENGTH, TUBE_OUTER_DIAMETER, TUBE_INNER_DIAMETER, TUBE_THICKNESS);

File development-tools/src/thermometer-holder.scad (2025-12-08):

/**
 * Thermometer Holder for Darkroom Containers
 *
 * A clip-on holder that attaches to container rims and holds a thermometer.
 * Optimized for 3D printing - no supports needed when printed on its side.
 */

include <BOSL2/std.scad>

/* [Thermometer Dimensions] */
// Diameter of thermometer shaft (mm)
Thermometer_Diameter = 4; // [1:0.5:15]

// Extra clearance for thermometer fit (mm)
Thermometer_Clearance = 0.5; // [0.2:0.1:1.5]

/* [Container Dimensions] */
// Thickness of container rim (mm)
Container_Rim_Thickness = 2; // [0.5:0.5:10]

// Depth of container rim hook (mm)
Container_Rim_Depth = 15; // [8:1:30]

// Extra clearance for container rim (mm)
Rim_Clearance = 0.5; // [0.2:0.1:2]

/* [Holder Dimensions] */
// Length of horizontal arm (mm)
Arm_Length = 60; // [40:5:120]

// Width of the holder (mm)
Holder_Width = 15; // [10:1:25]

// Thickness of material (mm)
Material_Thickness = 4; // [3:0.5:8]

/* [Rendering] */
$fn = 48;

// Calculated values
therm_hole_dia = Thermometer_Diameter + Thermometer_Clearance * 2;
rim_slot_width = Container_Rim_Thickness + Rim_Clearance * 2;
hook_total_width = rim_slot_width + Material_Thickness * 2;
hook_height = Container_Rim_Depth + Material_Thickness;

/**
 * Main thermometer holder - single unified shape
 */
module thermometer_holder() {
    difference() {
        // Main body as linear extrusion of 2D profile
        rotate([90, 0, 0])
            linear_extrude(height=Holder_Width, center=true)
                holder_profile();

        // Thermometer hole
        therm_hole_x = therm_hole_dia / 2 + 8;
        translate([therm_hole_x, 0, Material_Thickness / 2])
            cylinder(h=Material_Thickness + 2, d=therm_hole_dia, center=true);
    }
}

/**
 * 2D profile of the holder (view from the side)
 */
module holder_profile() {
    // Where the hook begins (inner wall)
    hook_inner_x = Arm_Length - hook_total_width;

    union() {
        // Horizontal arm
        square([Arm_Length, Material_Thickness]);

        // Hook - outer vertical (hangs down from arm)
        translate([Arm_Length - Material_Thickness, -hook_height + Material_Thickness])
            square([Material_Thickness, hook_height]);

        // Hook - inner vertical (shorter, creates the open U-shape for rim)
        // This piece only extends down partway to leave bottom open
        translate([hook_inner_x, -Container_Rim_Depth])
            square([Material_Thickness, Container_Rim_Depth + Material_Thickness]);

        // Support brace
        brace_top_x = therm_hole_dia + 12;
        brace_bottom_y = -Container_Rim_Depth;

        polygon(
            [
                [brace_top_x, 0], // Top left of brace
                [brace_top_x + Material_Thickness, 0], // Top right
                [hook_inner_x + Material_Thickness, brace_bottom_y], // Bottom right (connects to inner hook)
                [hook_inner_x, brace_bottom_y], // Bottom left
            ]
        );
    }
}

// Render the holder
rotate([90, 0, 0]) thermometer_holder();

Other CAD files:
lens-boards/src/intrepid-lens-board.scad
lens-boards/src/common/lens-sizes.scad
negative-carriers/carrier-baked.scad
negative-carriers/carrier.scad
negative-carriers/src/beseler-23c-base-shape.scad
negative-carriers/src/beseler-23c.scad
negative-carriers/src/beseler-45-base-shape.scad
negative-carriers/src/carrier-configs.scad
negative-carriers/src/common/beseler-23c-alignment-board.scad
negative-carriers/src/common/carrier-features.scad
negative-carriers/src/common/film-sizes.scad
negative-carriers/src/common/lpl-saunders-alignment-board.scad
negative-carriers/src/common/omega-d-alignment-board.scad
negative-carriers/src/common/text-etching.scad
negative-carriers/src/common/universal-carrier-assembly.scad
negative-carriers/src/lpl-saunders-45xx.scad
negative-carriers/src/lpl-saunders-base-shape.scad
negative-carriers/src/old/beseler-23c.scad
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

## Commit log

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2025-05-02 Refactor omega-lpl.scad to include customizable film format options and enhance carrier design with new parameters for registration holes and alignment screws.
    [omega-lpl.scad]
2025-05-03 Refactor omega-lpl.scad to modularize shape creation, improving readability and maintainability. Simplify film format handling by removing unused custom dimensions and enhance peg feature implementat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
    [beseler-23c.scad, common-carrier-features.scad, film-sizes.scad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]
2025-05-03 Increase resolution for smoother rendering in beseler-23c.scad and reposition alignment circle for improved carrier design.
    [beseler-23c.scad]
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2025-05-05 Update alignment screw holes in omega-lpl.scad to support optional dent feature, enhancing design flexibility. Adjust Y offset for registration hole cylindrical parts for improved accuracy.
    [omega-lpl.scad]
2025-05-05 Enhance film format handling in omega-lpl.scad by adding support for filed formats and custom dimensions. Introduce new parameters for medium format heights and widths, and update type name selection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
    [omega-lpl.scad]
2025-05-05 Refactor omega-lpl.scad to introduce orientation handling for vertical and horizontal layouts. Update peg gap logic for improved flexibility and adjust test piece dimensions based on orientation, enh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
    [omega-lpl.scad]
2025-05-06 Update film sizes and enhance omega-lpl.scad with improved film format handling. Adjust medium format dimensions, introduce new parameters for custom film formats, and refine peg and alignment screw 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
    [film-sizes.scad, omega-lpl.scad]
2025-05-06 Enhance beseler-23c.scad with customizable carrier options, including film format selection, orientation handling, and owner/type name etching features. Introduce new parameters for peg gap and film 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
    [beseler-23c.scad, common-carrier-features.scad, film-sizes.scad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]
2025-05-07 Update README.md with detailed project description, installation instructions, configuration guidelines, and usage examples. Remove holder-types.scad as it is no longer needed.
    [omega-d-alignment-board.scad]
2025-05-07 Enhance beseler-23c.scad with new film opening parameters and improved logic for determining actual opening dimensions based on orientation. Integrate common carrier features and refine handle and ba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
    [beseler-23c.scad, film-sizes.scad, lpl-saunders-45xx.scad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]
2025-05-07 Adjust z_offset calculation in omega-d.scad for bottom orientation by adding a small increment to improve alignment accuracy.
    [omega-d.scad]
2025-05-07 Add heat-set peg hole and socket head opening modules in common-carrier-features.scad; refactor omega-d-alignment-board.scad to separate screw and no-screw variants; update omega-d.scad to include al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
    [common-carrier-features.scad, omega-d-alignment-board.scad, omega-d.scad]
2025-05-07 Refactor omega-d.scad to introduce a common_subtractions module for improved code organization and reuse. Update logic for bottom and top piece handling, ensuring correct peg features and etching bas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
    [omega-d.scad]
2025-05-07 Update film format options in omega-d.scad by removing custom film height and width parameters. Adjust comments for clarity and ensure compatibility with alignment board settings.
    [omega-d.scad]
2025-05-07 Moved files: common-carrier-features.scad, film-sizes.scad, and omega-d-alignment-board.scad. Update omega-d.scad to reference new common file paths for film sizes and alignment board features, ensur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
    [carrier-features.scad, film-sizes.scad, lpl-saunders-alignment-board.scad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]
2025-05-08 Refactor beseler-23c.scad to enhance alignment board integration and improve film opening parameters. Introduce new options for peg types and alignment board selection, ensuring compatibility with pr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
    [beseler-23c-alignment-board.scad, beseler-23c.scad, carrier-features.scad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]
2025-05-08 Update beseler-23c.scad to comment out the Alignment_Board_Type variable and replace alignment_circle() with beseler_23c_alignment_board() for improved clarity and functionality in alignment board ha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
    [beseler-23c.scad]
2025-05-08 Refactor carrier generation logic across beseler-23c.scad, lpl-saunders-45xx.scad, and omega-d.scad to utilize a new carrier_base_processing module for improved organization and maintainability. This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
    [beseler-23c.scad, carrier-features.scad, lpl-saunders-45xx.scad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]
2025-05-08 Add screw hole parameters to lpl-saunders-alignment-board.scad for enhanced assembly options. Introduced variables for screw diameter, hole dimensions, and locations to improve design flexibility and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
    [lpl-saunders-alignment-board.scad]
2025-05-09 Add custom film format parameters to lpl-saunders-45xx.scad, enabling support for user-defined film dimensions. Updated film opening logic to accommodate custom sizes, enhancing flexibility in film f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
    [film-sizes.scad, lpl-saunders-45xx.scad]
2025-07-08 Update .gitignore to include .vscode and JSON files. Modify omega-d.scad to adjust peg z-offset and alignment board translation values for improved accuracy. Remove obsolete beseler-23c-lift file.
    [omega-d.scad]
2025-08-26 Enhance omega-d.scad for multi-material printing by introducing parameters for text rendering and solid generation. Implement logic for separate text parts, allowing for customizable etching depths a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
    [carrier-features.scad, omega-d.scad]
2025-08-26 Enhance carrier generation in beseler-23c.scad, lpl-saunders-45xx.scad, and omega-d.scad by introducing a Flip_Bottom_For_Printing parameter for improved print orientation. Refactor bottom carrier as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
    [beseler-23c.scad, carrier-features.scad, lpl-saunders-45xx.scad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]
2025-08-26 Enhance lpl-saunders-45xx.scad and omega-d.scad by integrating shared text etching functionality. Refactor text validation and generation logic for multi-material printing, ensuring consistent text h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
    [lpl-saunders-45xx.scad, omega-d.scad, text-etching.scad]
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2025-12-09 fix: Adjust rotary stick holder height and position in tube.scad
    This commit modifies the height of the rotary stick holder from 15 to 7 and updates its vertical position in the tube module to ensure proper alignment within the patterson tank.
    [tube.scad]
2026-03-31 fix: Center text etching using textmetrics, independent of film format
    Text position was dependent on opening_width, causing it to shift when
    changing film formats. Long names like "AMANDA" would also overflow the
    carrier edge. Now uses textmetrics to measure actual text width and
    positions each text with equal edge margin from the carrier boundary.
    [carrier-configs.scad, text-etching.scad, universal-carrier-assembly.scad]
2026-03-31 fix: Rotate 6x6 direction indicator triangle based on orientation setting
    The directional arrow for 6x6 film formats was always rendered in the
    vertical orientation regardless of the Orientation setting. Pass the
    actual orientation through to the arrow generation and reposition the
    arrow to the right side of the opening for horizontal orientation.
    [carrier-features.scad, carrier.scad, universal-carrier-assembly.scad]
2026-03-31 refactor: Optimize carrier code and add Beseler 23C bottom text etching
    Code optimizations across all carrier modules:
    - Replace duplicated peg/screw/edge-cut geometry with for loops
    - Extract parameterized screw_hole_quad() and reg_hole() modules
    - Consolidate text rotation logic and Z-offset lookup table
    - Share Beseler 23C constants via carrier-configs.scad
    - Name magic numbers (arrow offset, separation hole, torus radii)
    - Cap large body geometry at $fn=72 for faster renders
    - Remove dead code and update stale docstrings
    Beseler 23C bottom carrier text:
    - Etch text on bottom surface (opposite alignment board)
    - Apply mirror([0,1,0]) so text reads correctly after 180° print flip
    - Negat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
    [beseler-23c-alignment-board.scad, beseler-23c-base-shape.scad, carrier-configs.scad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]
2026-06-29 fix: Lower rotary stick holder height and position in tube
    [tube.scad]
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2026-06-29 docs: Amend Plan 1 — defer Manifold, v1 ships on fast-csg (gate passed)
    Manifold build hit a chain of openscad-wasm upstream breakages (dead GMP
    mirror, CMake version conflicts) with no clear end. The textmetrics risk is
    retired on fast-csg (text renders correctly), so v1 ships on scadder's
    importable build and tracks a deferred Manifold-upgrade task.
    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
2026-06-29 docs: Add Plan 2 (Guided Customizer UI & Live Preview) for DarkroomSCAD Web
    6-task plan: curation overlay + schema-drift check, schema-driven form with
    conditional visibility, debounced newest-wins preview controller, react-three-
    fiber STL viewer, and the assembled customizer page with live preview. Baseline
    dorkroom dark styling; export/full-theming/deploy deferred to Plan 3.
    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
2026-06-29 docs: Add Plan 4 (Export & Deploy) for DarkroomSCAD Web
    5-task plan: part enumeration (top/bottom + multi-material text parts), a
    multi-part export controller that skips empty renders and zips via fflate, an
    export panel (ZIP set default / individual files), the deferred Plan 3 polish
    (slider units + no-flash hardening), and Vercel deploy using the spec's
    GitHub-raw pinned-ref source model (DarkroomSCAD is public on GitHub). Deploy
    is user-gated.
    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
2026-06-30 fix(boards): 4x5 omega opening clears film + screws; beseler includes BOSL2
    - Omega-D alignment board: widen the 4x5 left-right opening to 121mm
    (clears the 120mm 4x5 film opening, 3mm outer rail) and slim the
    top-bottom notch (97mm width / 105mm height) so the opening no longer
    overlaps the alignment screws and corner rails stay ≥~3.9mm.
    - Beseler-23C alignment board: add `include <BOSL2/std.scad>` (uses
    torus(); matches the omega/lpl board files which already include it),
    so it resolves when used standalone.
    [beseler-23c-alignment-board.scad, omega-d-alignment-board.scad]
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2026-06-30 fix(baked): thread Custom_* film-format params into the baked preview
    carrier-baked.scad never declared the Custom_Film_Width/Height and
    Custom_Opening_Width/Height params and called get_custom_aware_opening_*
    and get_film_format_peg_distance without them, so the "custom" film format
    always fell back to the 37x37 square default — custom-size sliders did
    nothing in the live preview. Pass them through exactly as carrier.scad does
    so the baked path matches the parametric path for custom dimensions.
    [carrier-baked.scad]
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2026-07-02 fix(beseler-45): punch top film-peg holes through the 2.5mm board (z-offset 1->2)
    [carrier-configs.scad]
2026-07-02 feat(beseler-45): add fixed corner alignment/stacking pegs (bottom) + holes (top)
    [carrier-configs.scad, universal-carrier-assembly.scad]
2026-07-02 feat(beseler-45): etch owner/type text on the top handle
    Adds a beseler-45 branch to calculate_text_position/get_text_rotation
    (universal-carrier-assembly.scad) and _get_text_settings
    (carrier-configs.scad) so owner/type text lands on the top (+Y) handle
    instead of falling through the generic disc-edge branch.
    Rotation stays [0,0,90] as specified, but the pre-rotation position had
    to be [handle_mid_y, -x_base] rather than [x_base, handle_mid_y]: the
    caller applies rotate(rotation) as the OUTER transform around
    translate(position), so world_position = R(rotation) * position, not
    position itself. Verified empirically with camera markers before fixing;
    literal [x_base, handle_mid_y] placed tex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
    [carrier-configs.scad, universal-carrier-assembly.scad]
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2026-07-02 fix(beseler-45): corner alignment pegs protrude down only (enlarger side)
    [carrier-configs.scad, universal-carrier-assembly.scad]
2026-07-02 fix(beseler-45): reduce corner peg protrusion to 2mm
    [carrier-configs.scad]
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2026-07-02 fix(beseler-45): cut bottom heat-set insert holes through the 2.5mm board
    [universal-carrier-assembly.scad]
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2026-07-02 fix(beseler-45): move handle to the left (-X) to match the canonical carrier layout
    Every other carrier generates with its handle on the left, and the shared
    vertical/horizontal orientation logic assumes that frame. The Beseler 45's
    top (+Y) handle made the Orientation toggle read flipped (horizontal was
    vertical relative to the carrier). Rotate the handle to -X like the
    Beseler 23C and move the etch text onto the left handle as two horizontal
    rows (owner top, type bottom, mirrored for the bottom part like the 23C).
    The corner alignment pegs are a symmetric square, so they are unaffected.
    [beseler-45-base-shape.scad, carrier-configs.scad, universal-carrier-assembly.scad]
2026-07-02 fix(4x5): force horizontal orientation — long edge perpendicular to the handle
    With the handle-left layout, the 4x5 sheet's long (5", 120mm) edge should
    run along Y, perpendicular to the handle, matching how the sheet sits in
    the enlarger. get_effective_orientation now forces "horizontal" for 4x5
    (the Orientation option remains a no-op for 4x5), and the Omega D
    alignment board rotates its 4x5-widened opening 90 deg to follow.
    [carrier-features.scad, omega-d-alignment-board.scad]
2026-09-16 fix(lpl-saunders): seat the LPL alignment board flush against the carrier underside
    The board was translated by -carrier_height, but the board module's flat
    mounting face sits at z=-0.05 in its own coordinates, so the board ended up
    1.05mm below the carrier as a separate, floating solid (lpl-saunders-45xx and
    beseler-23c carriers with the lpl-saunders board). Name the mounting face
    (LPL_BOARD_MOUNT_FACE_Z) and seat it on the carrier underside, sunk 0.05mm
    so the union is a single body. omega-d's embed offset is unchanged.
    [lpl-saunders-alignment-board.scad, universal-carrier-assembly.scad]
2026-09-16 fix(pegs): reduce filed-format peg clearance to 0.5mm per side
    Filed formats pushed the alignment pegs out a full 1mm per side beyond the
    standard formats. Halve that via a named FILED_PEG_EXTRA_GAP constant so the
    pegs sit a bit closer to the film edge.
    [carrier-features.scad]
2026-09-16 feat(film-sizes): add "half frame filed"; fold "35mm full" into "35mm" (36x24)
    - New "half frame filed" format (21x28, FILEDHALF): 19mm half-frame pitch + 2mm
    along the strip and 24->28 across, the same rebate reveal as "35mm filed".
    Gets the 0.5mm filed peg clearance in calculate_internal_peg_gap.
    - "35mm" is now the exact 36x24 frame. Its 37mm height came from reusing
    thirtyFiveFullHeight (the strip-width/peg-distance constant) as the opening
    height, not from a deliberate carrier dimension; "35mm full" (36x24, FULL35)
    was the intended size, so it is removed and "35mm" takes its dimensions.
    [carrier-features.scad, carrier.scad, film-sizes.scad]
2026-09-17 fix(pegs): clear the film edge on 120 and 4x5; add 0.25mm edge clearance
    Peg distance is stock width + 2 (the peg calc subtracts 1mm back per side), but
    the 120 (62) and 4x5 (102) constants omitted that bias, putting printed pegs
    1mm inside the film per side (60mm between pegs vs 61-61.5mm film; 100 vs
    ~101.6). Express the constants as actual stock widths (35 / 61.5 / 101.6) plus
    a named bias, and add a 0.25mm per-side FILM_EDGE_CLEARANCE (= PEG_HOLE_TOLERANCE)
    so the top piece's oversized peg hole clears the film as well.
    Between pegs: 35mm 35.0 -> 35.5, 120 60.0 -> 62.0, 4x5 100.0 -> 102.1.
    [film-sizes.scad]
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2026-09-17 feat(omega-d): add single-piece 4x5 glass plate carrier
    New Carrier_Type "omega-d-glass": one 4mm slab (two halves' worth) with the
    Omega-D outline and registration holes, a 102x127 pocket on the top face for
    a 101x126 glass plate (0.5mm play per side, 2.2mm deep for 1.8-2.0mm plates)
    over the 4x5 film opening, and a Ø16 finger notch at one pocket corner that
    sits beside the plate and reaches 2.5mm under its edge, cut 1.2mm below the
    pocket floor, so the plate can be lifted out. No film pegs (the pocket
    locates the plate), never flipped for printing (pocket faces up so it prints
    without supports), and the alignment board is screwed on rather than fused.
    The universal 82x113 screw footprint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
    [carrier-configs.scad, carrier.scad, omega-d-base-shape.scad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]
2026-09-17 fix(export): make _Render_Alignment_Board_Only reachable from parameter sets
    OpenSCAD parameter sets (-p/-P) skip variables declared in a [Hidden]
    group, and the standalone-board export flag lived there — so exporting the
    board through a parameter set (which the web app does) rendered the whole
    carrier instead of the board, for every carrier type. Move the flag into a
    visible [Output Selector] group next to _WhichPart.
    [carrier.scad]
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2026-09-21 feat(pegs): heat-set screw head style presets and custom head diameter
    The top carrier's hole registers on the peg screw's head, so its diameter has
    to match the screws actually used. Add HEAT_SET_SCREW_HEADS (ISO dk max per
    head style x size: socket cap ISO 4762, button ISO 7380, pan ISO 7045, cheese
    ISO 1207) and two customizer params:
    - Heat_Set_Screw_Head ("socket" | "button" | "pan" | "cheese" | "custom")
    - Heat_Set_Screw_Head_Diameter (measured head, used for "custom")
    carrier.scad now resolves size / head / adjusts into two hole diameters once
    and the peg chain carries those (heat_set_thread_hole_dia /
    heat_set_head_hole_dia) instead of the raw settings. Defaults are unchanged
    (M2 s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
    [carrier-baked.scad, carrier-features.scad, carrier.scad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]
2026-09-21 fix(alignment): per-board screw footprint for LPL-Saunders and Beseler 23C boards
    When the alignment board is not fused, the carrier gets four screw holes so it
    can be screwed onto the separately printed board. Those holes used the Omega D
    board's 82x113 pattern for every board type, which lands in empty space on the
    LPL-Saunders board (its two chord rails sit at |x| = 60.5..75.4) and the
    Beseler 23C board got no holes at all.
    The pattern now follows the board type (get_alignment_screw_pattern_dist_*
    take it as a second argument; the glass carrier keeps its own):
    - omega: 82 x 113 -> (±41, ±56.5) on the square frame's rails
    - lpl-saunders: 136 x 70 -> (±68, ±35), centred on the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
    [carrier-baked.scad, carrier-configs.scad, universal-carrier-assembly.scad]
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2026-09-22 feat(alignment): omega board pilot holes; size every footprint hole from the heat-set screws
    - All alignment-footprint holes (carrier bottom through-holes, top dents) and
    the standalone board's pilot holes are the heat-set thread-forming size
    (heat_set_thread_hole_dia: Heat_Set_Screw_Size + Heat_Set_Thread_Hole_Adjust;
    M2 1.9mm) — the footprint screws are the same screws as the pegs. Drops the
    fixed UNIVERSAL_ALIGNMENT_SCREW_DIAMETER = 2 and ALIGNMENT_BOARD_SCREW_PILOT_DIA.
    - The glass carrier's board clearance hole follows the size too
    (heat_set_clearance_hole_dia = nominal + 0.4; M2 2.4 as before). The screw
    size table gains the nominal thread diameter.
    - The standalone omega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
    [beseler-23c-alignment-board.scad, carrier-baked.scad, carrier-configs.scad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]
2026-09-22 feat(glass): counterbore the screw-on alignment board's holes for the screw heads
    The glass carrier's separately printed board had plain clearance holes, so
    the M2 heads stood their full height proud of the 1.7mm board. Cut a
    counterbore from the outer (+Z) face, sized like the top carrier's head
    hole (head + 0.5), so the heads sit mostly inside the board.
    New customizer param Glass_Board_Screw_Counterbore (default 1mm, 0 = none,
    capped at 1.2 so some floor is always left under the head).
    [carrier.scad, omega-d-glass-base-shape.scad]
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

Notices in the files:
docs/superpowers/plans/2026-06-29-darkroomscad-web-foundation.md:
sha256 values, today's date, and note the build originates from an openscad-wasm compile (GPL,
